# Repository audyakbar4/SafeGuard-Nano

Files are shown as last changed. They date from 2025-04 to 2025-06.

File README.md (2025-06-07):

# 🌱 MoodPot — *"Happy Plant, Happy You."*

[Baca dalam Bahasa Indonesia](README.md) | [🌐 Read in English](README_EN.md)

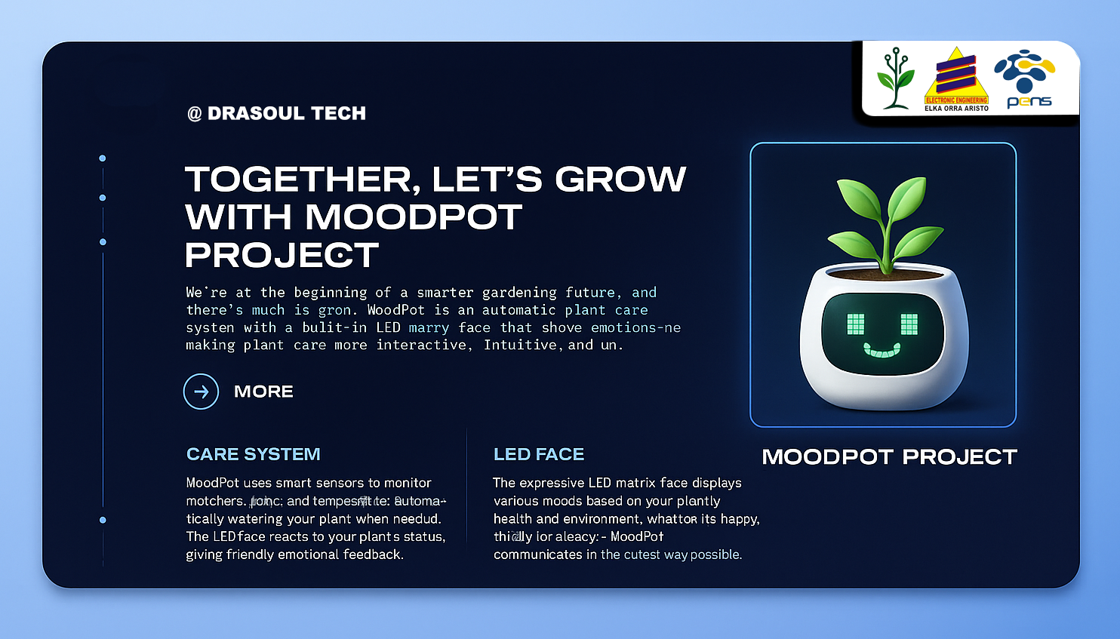
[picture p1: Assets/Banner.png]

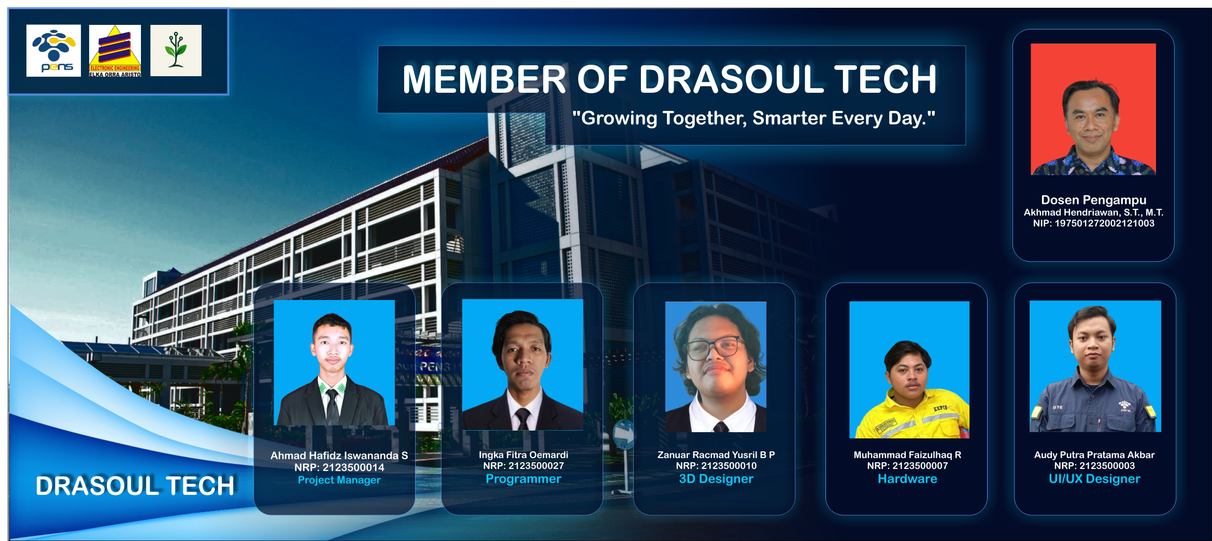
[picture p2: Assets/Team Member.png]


---

## 🎬 Commercial Video

Watch the demo (https://youtu.be/-DmmOEKwArI)

## Read The Book Now

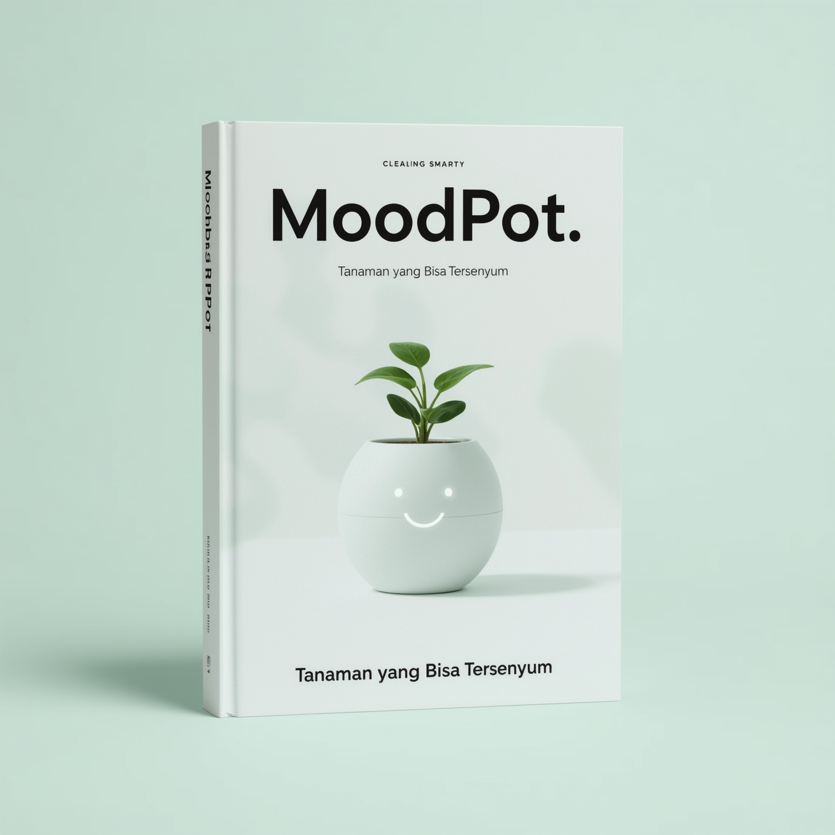
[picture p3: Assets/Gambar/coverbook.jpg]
Buka Buku (https://drive.google.com/file/d/1HuYGjgtTOYwcRgPvUPsH1EMrSk2Qgu1x/view?usp=drive_link)


## 🎬 Demo Video Project

Watch the demo (https://youtu.be/0xyM6YmwgGI)

##  Overview

🌱 MoodPot – Ketika Tanaman Bisa Bercerita Lewat Ekspresi

Pernah merasa bersalah karena lupa menyiram tanaman? Atau bingung kapan waktunya menyiram? MoodPot hadir sebagai sahabat tanaman yang bisa berbicara padamu lewat ekspresi wajah.

Bayangkan kamu pulang ke rumah setelah hari yang melelahkan. Di pojok ruangan, tanaman kesayanganmu sedang “menatap” dengan wajah sedih. Bukan karena marah—tapi karena ia haus. Tapi tenang, MoodPot sudah tahu apa yang harus dilakukan. Ia otomatis menyalakan pompa kecil dan memberi tanamanmu minuman yang dibutuhkannya.

Beberapa saat kemudian, wajahnya berubah ceria. Tanahnya lembap kembali, dan tanamanmu pun bahagia.

MoodPot bukan sekadar pot bunga. Ia adalah teman kecil yang mengingatkan kita bahwa merawat tanaman bisa menjadi pengalaman yang menyenangkan, komunikatif, dan penuh empati—bahkan untuk pemula sekalipun. Dengan sensor kelembapan tanah, ekspresi LED Matrix yang menggemaskan, dan sistem penyiraman otomatis, MoodPot menjadikan setiap interaksi kecil terasa berarti.

Karena tanaman juga punya cara untuk menyampaikan perasaannya—dan MoodPot menerjemahkannya untukmu.

---

## 🎯 Objectives

- 🔍 Mendeteksi kelembapan tanah secara otomatis menggunakan sensor.
- 😊 Memberikan feedback visual (wajah senang/datar/sedih) melalui LED Matrix.
- 💧 Menyiram tanaman secara otomatis ketika tanah kering.
- 💻 Menyediakan monitoring kelembapan secara real-time melalui UART ke komputer.

---

## 🧠 Background

Merawat tanaman sering kali menjadi tantangan, terutama bagi orang-orang sibuk atau yang belum terbiasa dengan kebutuhan dasar tanaman. Salah satu penyebab tanaman layu adalah kurangnya perhatian terhadap kelembapan tanah.

**MoodPot** memberikan solusi dengan menampilkan *"mood"* tanaman—apakah bahagia, cukup, atau sedih—berdasarkan kondisi tanah, membuat pengguna lebih peduli dan terlibat.

---

## 🖼️ Preview Presentasi



> Klik tombol di atas untuk membuka presentasi secara penuh di Canva.

---

## 🧾 Daftar Isi Presentasi

1. Latar Belakang & Masalah
2. Konsep MoodPot
3. Komponen yang Digunakan
4. Diagram Sistem
5. Demo & Visualisasi
6. Manfaat dan Pengembangan

---

## 🔧 Hardware Components

| Komponen | Fungsi |
|---|---|
| 🧠 Arduino Nano | Pengontrol utama |
| 🌱 Sensor Kelembapan | Membaca kadar air tanah |
| 😃 LED Matrix (MAX7219) | Menampilkan ekspresi wajah |
| 🔌 Relay Module | Mengendalikan pompa |
| 💦 Pompa DC 5V | Menyiram tanaman otomatis |
| 🔋 Baterai 18650 2S | Sumber daya portabel |

---

## 💻 Software Tools

- [Arduino IDE](https://www.arduino.cc/en/software)
- [KiCad](https://kicad.org/)
- [Figma](https://www.figma.com/)
- [TinkerCAD](https://www.tinkercad.com/)
- [Thingiverse](https://www.thingiverse.com/)
- [Visual Studio Code](https://code.visualstudio.com/)

---

## 🧭 System Diagram

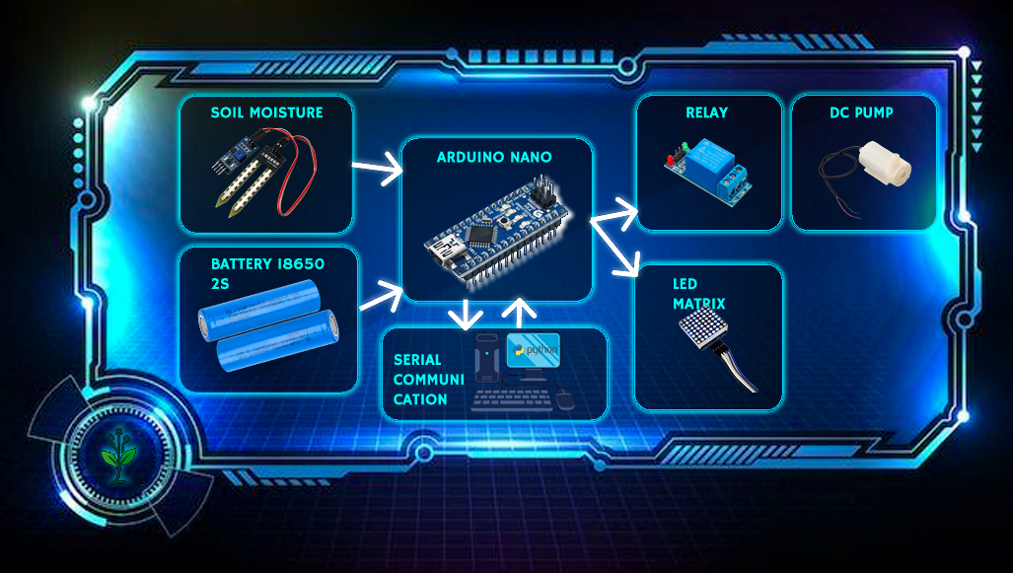
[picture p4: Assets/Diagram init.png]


## Schematic

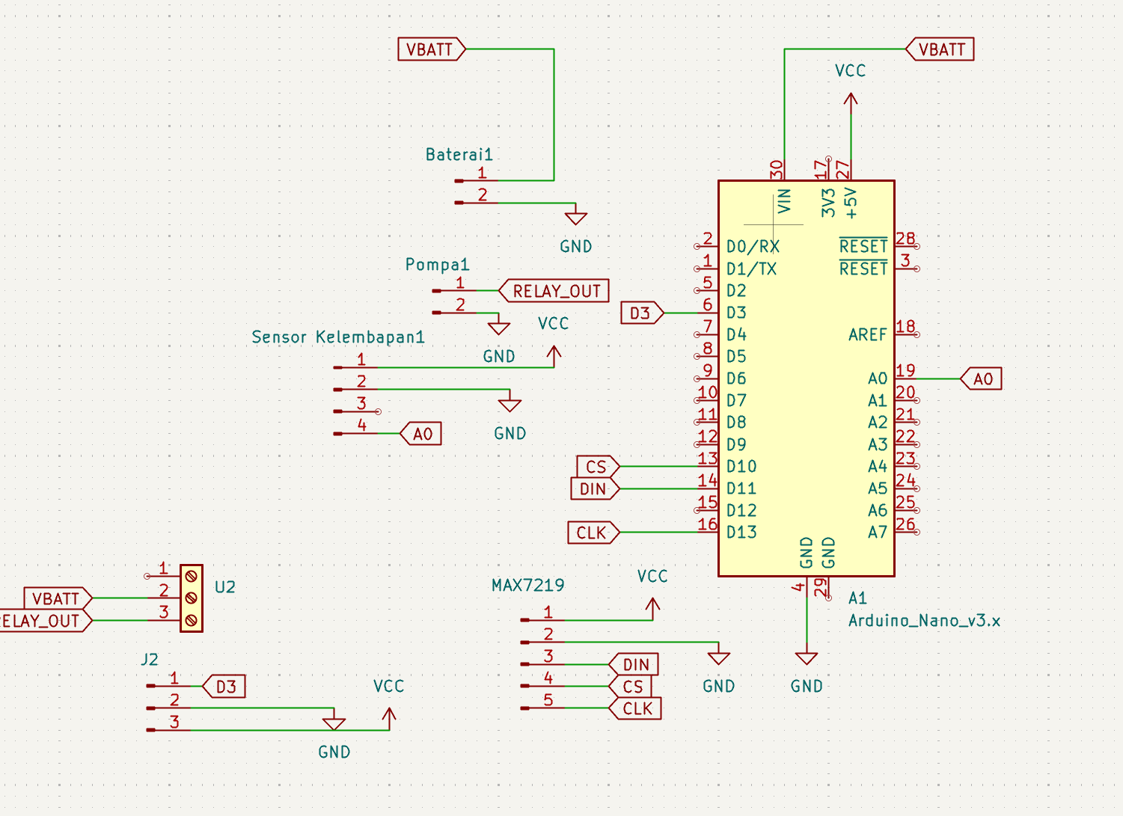
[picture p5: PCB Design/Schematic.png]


## Layout

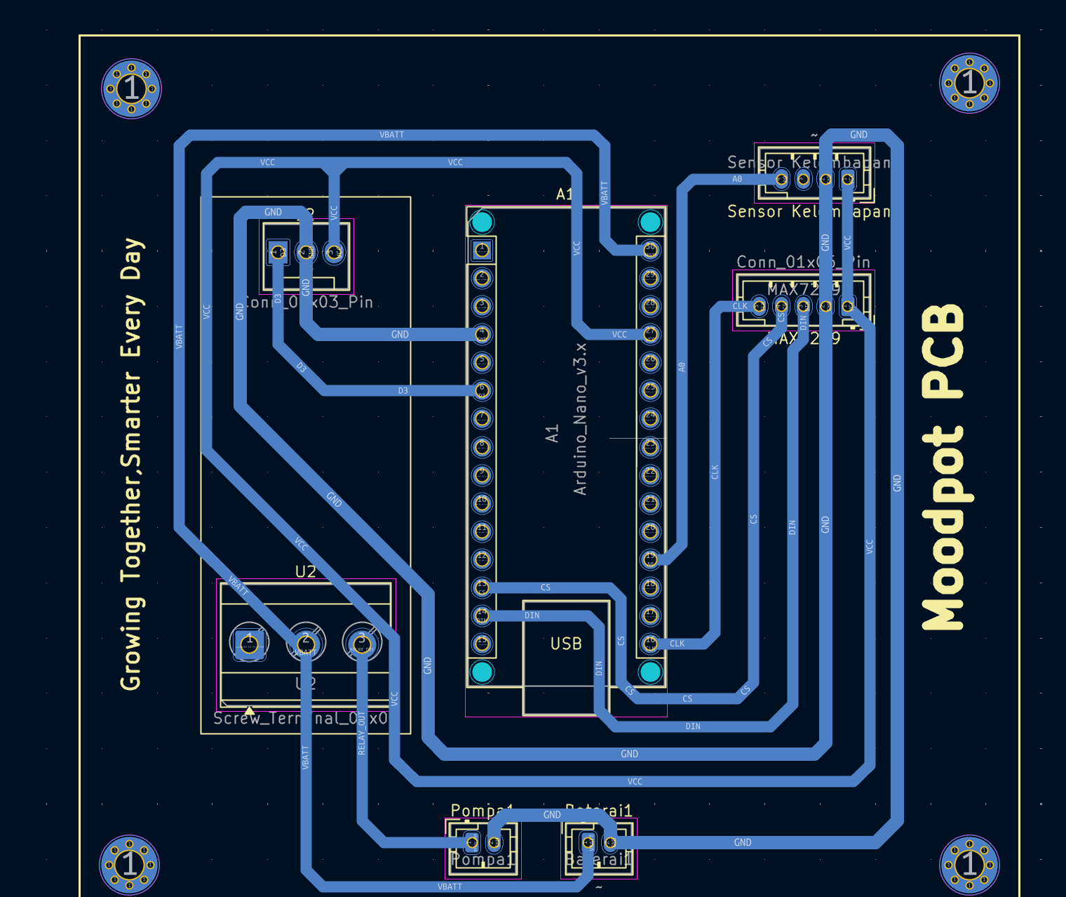
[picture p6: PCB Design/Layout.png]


## 3D PCB

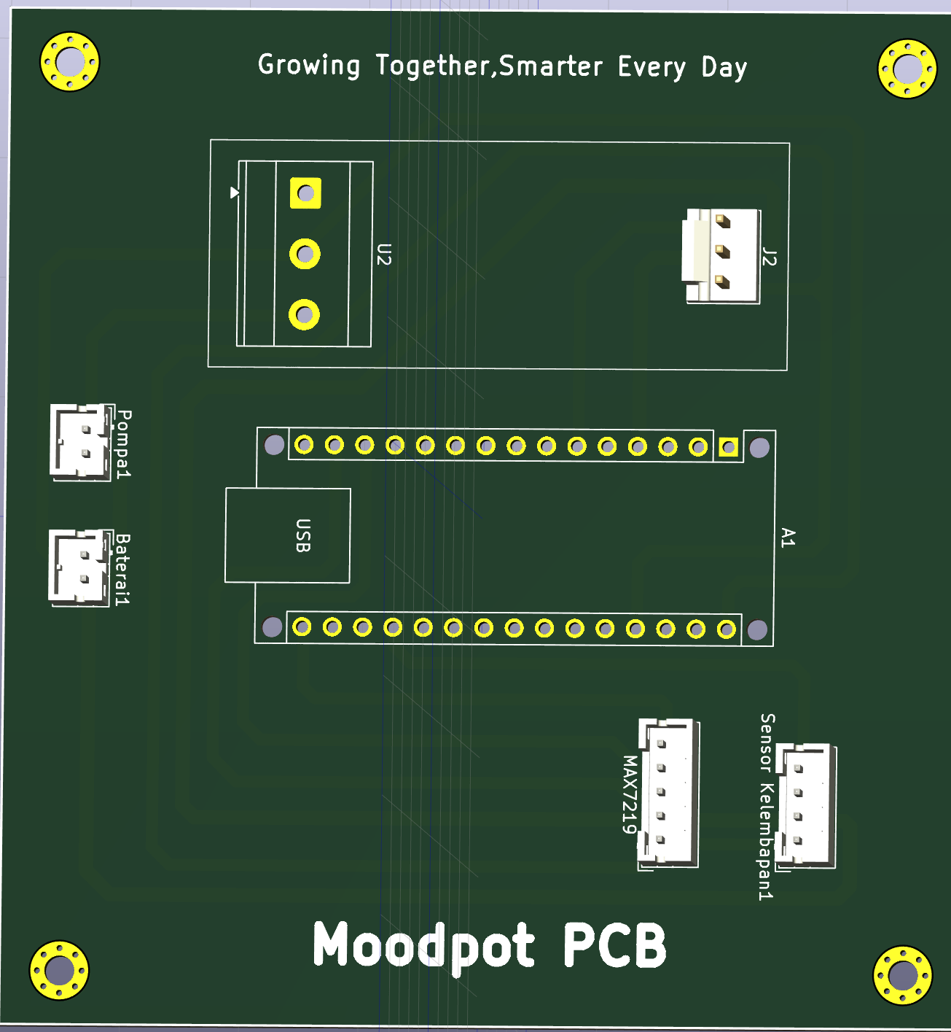
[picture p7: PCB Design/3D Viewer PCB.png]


## Tampak Dalam
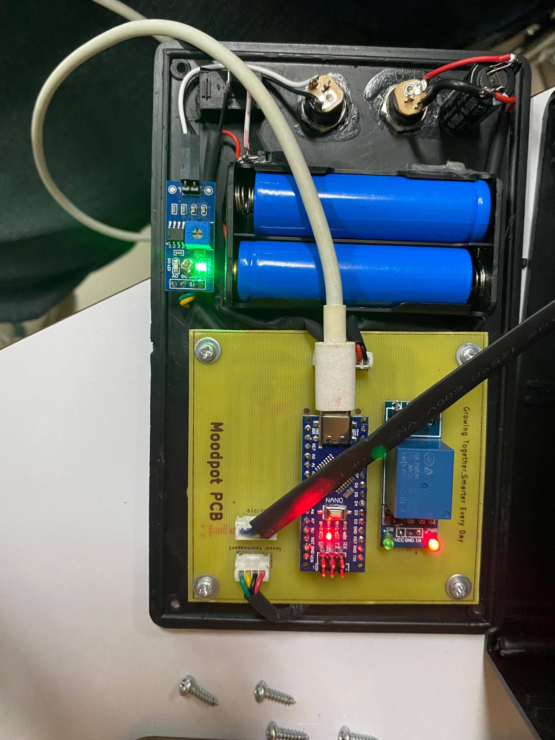
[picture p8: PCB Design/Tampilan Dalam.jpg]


---

## 💡 Simulasi Proyek



🔗 **Tautan Proyek Wokwi**  
[https://wokwi.com/projects/431816390638291969](https://wokwi.com/projects/431903301521434625)

📁 **Dokumentasi Proyek (Google Drive)**  
[https://drive.google.com/drive/folders/1GqONTiI6WEsIznY9d5Q_FcgnjMObSm_b?usp=drive_link](https://drive.google.com/drive/folders/1GqONTiI6WEsIznY9d5Q_FcgnjMObSm_b?usp=drive_link)

## 📄 Desain 3D

📁 **Tutorial Desain 3D (Google Drive)**

[👉 Klik di sini untuk membuka folder Google Drive](https://drive.google.com/drive/folders/1GnPXin400DgNMjtPwBu-FTDF2DJWISpB?usp=drive_link)

🔗 **Desain 3D Vol 1**  
https://www.thingiverse.com/thing:7030558

🔗 **Desain 3D Vol 2**  
https://www.thingiverse.com/thing:7048423

🔗 **Desain 3D Vol **  
https://www.thingiverse.com/thing:7050436

---

## ⚙️ Working Principle

### 🔍 Pembacaan Kelembapan
- Sensor kelembapan tanah mengirim sinyal analog ke Arduino.
- Nilai tinggi → tanah kering; nilai rendah → tanah basah.

### 🧠 Pemrosesan oleh Arduino
- Arduino membaca sensor secara berkala dan membandingkan dengan nilai *threshold*.
- Keputusan diambil untuk menyiram atau tidak.

### 😃 Feedback Visual
- Tanah basah  → LED Matrix menampilkan wajah senang 😊
- Tanah Sedang → LED Matrix menampilkan wajah Datar  😑
- Tanah kering → LED Matrix menampilkan wajah sedih  😢

### 💧 Penyiraman Otomatis
- Jika tanah kering, relay mengaktifkan pompa air.
- Setelah tanah cukup lembap, pompa dimatikan otomatis.

---
## 🚀 Quick Start

MoodPot dikirim dalam kondisi siap pakai (plug and play). Berikut langkah cepat untuk langsung menggunakannya:

### 🪴 Langkah Penggunaan MoodPot:

1. **Isi Tangki Air**
   - siapkan wadah untuk tangki air, isi wadah air hingga penuh kemudian masukkan dc pump / pompa air kedalam wadah yang sudah terisi dengan air.

2. **Colokkan Power**
   - Sambungkan MoodPot ke sumber daya menggunakan kabel USB atau baterai 2S 18650 bawaan.

3. **Tancapkan Sensor ke Tanah**
   - Pastikan sensor kelembapan sudah tertancap di dalam tanah pada pot tanaman kamu.

4. **Lihat Ekspresi Wajah**
   - MoodPot akan langsung menyala dan menampilkan ekspresi wajah:
     - 😊 Bahagia → Tanah lembap, tidak perlu disiram
     - 😐 Netral → Tanah mulai mengering, bersiap menyiram
     - 😢 Sedih → Tanah kering, pompa menyiram otomatis

5. **Selesai**
   - MoodPot akan bekerja otomatis 24/7 tanpa perlu pengaturan manual.

> 💡 Tips: Periksa tangki air setiap beberapa hari agar tidak kehabisan air.

---

## 👨‍💻 Team — Drasoul.Tech

| NRP | Nama Lengkap | Tanggung Jawab |
|---|---|---|
| 2123500003  | Audy Putra Pratama Akbar | UI/UX Designer |
| 2123500007  | Muhammad Faizulhaq R | Hardware |
| 2123500010  | Zanuar Rachmat Yusril B.P. | 3D Designer |
| 2123500014  | Ahmad Hafidz Iswananda S | Project Manager / Hardware  |
| 2123500027  | Ingka Fitra Oemardi | Programmer |

---
## 🌍 Showcase 

- 📢 Dipresentasikan di **PENS Workshop Mikrokontroler 2025**
- 🌟 Ditampilkan dalam demo terbuka oleh dosen pembimbing
- 👨‍🏫 Mendapat feedback positif dari pengajar dan rekan sejawat

📸 Dokumentasi Kegiatan:
[👉 Klik di sini untuk melihat dokumentasi](https://drive.google.com/drive/folders/1GqONTiI6WEsIznY9d5Q_FcgnjMObSm_b?usp=drive_link)

---

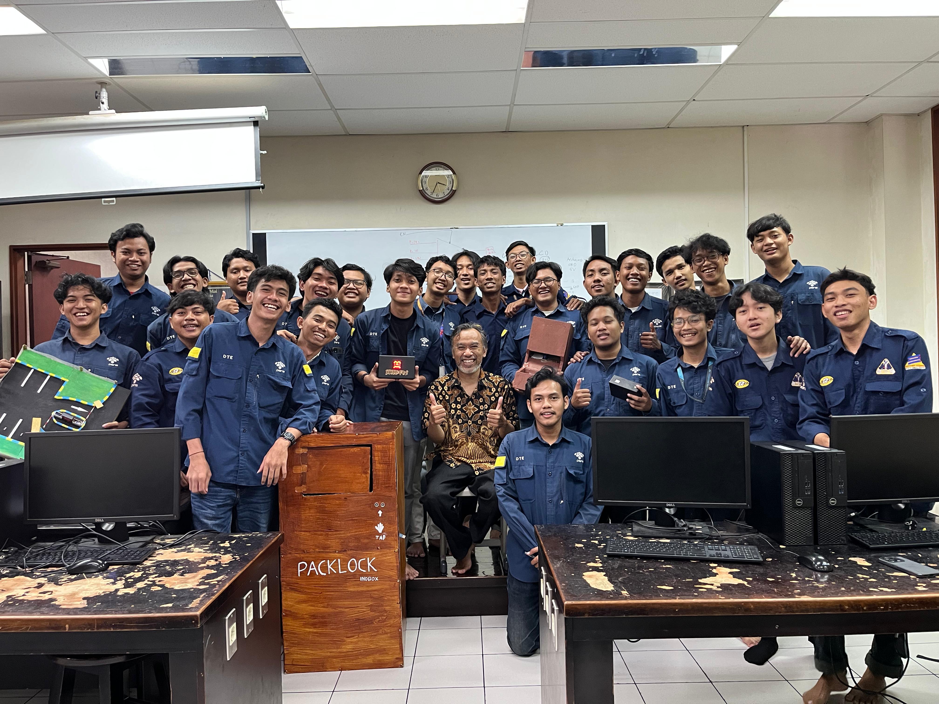
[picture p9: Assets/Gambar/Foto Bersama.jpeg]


## 🎓 Supported by

- 👨‍🏫 Dosen Pengampu: Akhmad Hendriawan, S.T., M.T.
- 📚 Mata Kuliah: Workshop Mikrokontroler
- 🏫 Institusi: Politeknik Elektronika Negeri Surabaya (PENS)
- 🧑‍🔧 Program Studi: Teknik Elektronika

---

## ✅ Future Improvements

- [ ] Tambahkan koneksi Bluetooth untuk kontrol dari HP
- [ ] Implementasi OLED display untuk info lebih lengkap
- [ ] Desain casing 3D cetak

---

## 📄 License

This project is licensed under the MIT License — see the [LICENSE](./LICENSE) file for details.

---

## 🙏 Credits

Developed with 💚 by **Drasoul.Tech**  
A project to bring life, tech, and plants together 🌿

## 📫 Contact Information

For inquiries related to this project — including collaborations, technical questions, or professional opportunities — feel free to reach out via email:

**📧 Email:** [yourname@example.com](mailto:yourname@example.com)

I aim to respond within 1–2 business days. Please include the project name in your subject line for faster reference.

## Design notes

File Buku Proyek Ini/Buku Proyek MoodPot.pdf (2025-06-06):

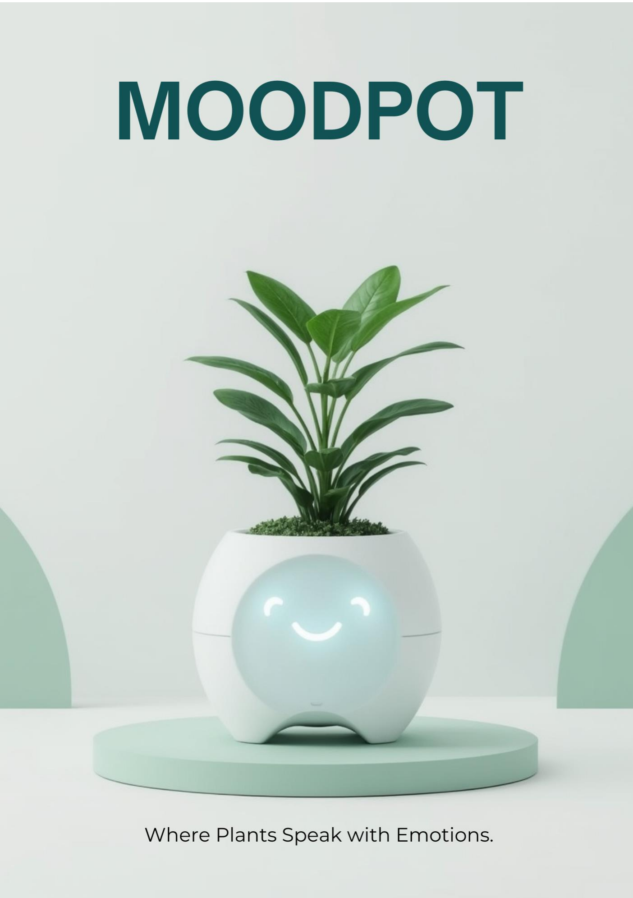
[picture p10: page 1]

Daftar Isi

BAB 1: Pendahuluan

BAB 2: Konsep dan Ideologi MoodPot

2.1 Inspirasi di Balik MoodPot

2.2 Filosofi "Tanaman Bisa Bercerita"

2.3 Konsep Interaksi Emosional antara Manusia dan Tanaman

2.4 Studi Kasus Penggunaan dalam Kehidupan Sehari-Hari

BAB 3: Perancangan Sistem MoodPot

3.1 Arsitektur Sistem secara Umum

3.2 Diagram Blok MoodPot

3.3 Alur Kerja MoodPot (Flowchart)

3.4 Skema dan Penjelasan Elektronik

BAB 4: Komponen Hardware

4.1 Arduino Nano: Otak dari MoodPot

4.2 Sensor Kelembapan Tanah

4.3 LED Matrix MAX7219: Ekspresi Wajah Tanaman

4.4 Pompa DC dan Relay: Mekanisme Penyiraman Otomatis

4.5 Sumber Daya: Baterai 18650 dan Manajemen Energi

BAB 5: Pemrograman MoodPot

5.1 Logika Program dan Penanganan Sensor

5.2 Menampilkan Ekspresi Wajah (Sad, Neutral, Happy)

5.3 Kontrol Pompa Berdasarkan Data Kelembapan

5.4 Monitoring Serial via UART

5.5 Optimalisasi dan Penanganan Error

BAB 6: Desain dan Estetika

6.1 Desain Fisik Pot dan Penempatan Komponen

6.2 Integrasi Teknologi dan Estetika

6.3 Desain UI Ekspresi LED Matrix

6.4 Visualisasi Figma dan TinkerCAD

BAB 7: Implementasi dan Pengujian

7.1 Proses Perakitan MoodPot

7.2 Pengujian Fungsi Otomatisasi Penyiraman

7.3 Respons Ekspresi terhadap Kelembapan

7.4 Studi Waktu Respons dan Efisiensi Air

7.5 Dokumentasi Proses Uji Lapangan

BAB 8: Dampak, Manfaat, dan Pengembangan

8.1 Pengaruh MoodPot terhadap Kebiasaan Merawat Tanaman

8.2 MoodPot untuk Edukasi Anak dan Pemula

8.3 Potensi Integrasi IoT dan Mobile App di Masa Depan

8.4 Pengembangan Ekspresi yang Lebih Kaya (Emotion Mapping)

8.5 Inovasi: MoodPot Versi Komunitas atau Sekolah

BAB 9: Penutup

9.1 Refleksi atas Proyek dan Pembelajaran

9.2 Saran untuk Pengguna dan Pengembang

9.3 Harapan ke Depan bagi MoodPot dan Proyek Serupa

Lampiran

- Kode Program Lengkap
- Skema Rangkaian
- Gambar PCB (jika ada)
- Tangkapan Layar Monitoring UART
- Daftar Komponen & Estimasi Biaya

# BAB 1

Merawat Tanaman di Era Digital
Di tengah deru kemajuan teknologi yang semakin pesat, kehidupan kita tak pernah lepas dari sentuhan inovasi. Mulai dari gawai cerdas hingga kendaraan otonom, semuanya dirancang untuk mempermudah setiap aspek kehidupan. Tak terkecuali dunia bercocok tanam. Dulu, merawat tanaman hanyalah tentang intuisi dan pengalaman. Kini, dengan hadirnya teknologi, kegiatan ini bisa menjadi lebih cerdas dan menyenangkan.
Bagi banyak orang, merawat tanaman, entah itu hamparan kebun yang luas atau sekadar pot bunga di beranda, bukan hanya sekadar hobi. Ada kepuasan tersendiri saat melihat tanaman tumbuh subur, bahkan ada manfaat psikologis dan ekologis yang tak ternilai. Namun, seringkali kesibukan harian, minimnya pengetahuan tentang kebutuhan spesifik tanaman, atau bahkan lupa, menjadi penghalang bagi kita untuk memberikan perhatian yang layak. Pernahkah Anda merasa bersalah karena tanaman kesayangan layu akibat telat disiram? Kita semua pernah mengalaminya.

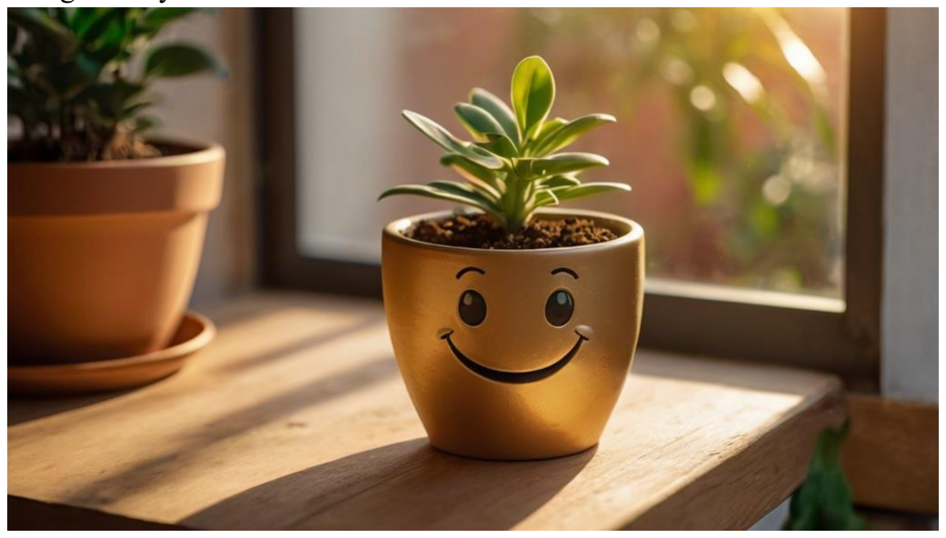
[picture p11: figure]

Di sinilah MoodPot hadir sebagai sebuah solusi inovatif dan empatik. Bayangkan sebuah pot tanaman yang bisa "berbicara" kepada Anda, bukan dengan suara, melainkan dengan ekspresi wajah! MoodPot adalah perpaduan cerdas antara teknologi mikrokontroler, sensor kelembapan tanah, dan layar LED Matrix yang mampu menampilkan ekspresi visual. Ini bukan sekadar alat penyiram otomatis biasa. MoodPot dirancang untuk membangun jembatan emosional antara Anda dan tanaman.

Ketika Tanaman Punya Ekspresi: Memahami Konsep MoodPot Melalui ekspresi wajah yang unik pada layar LED Matrix-nya, MoodPot
memberikan | gambaran | langsung
tentang kondisi tanaman. Sebuah
wajah | "sedih" | mungkin
menunjukkan bahwa tanaman Anda kehausan, dan begitu disiram, ia akan menampilkan wajah "bahagia" yang menggemaskan. Konsep ini melampaui fungsionalitas semata; ia menambahkan sentuhan emosional
yang | mengubah | pengalaman
merawat tanaman menjadi lebih
interaktif dan bermakna.

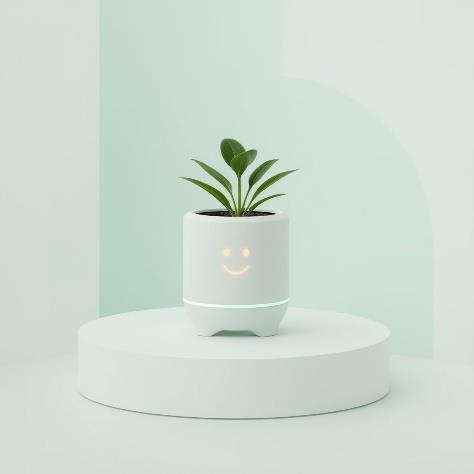
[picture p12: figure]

MoodPot bukan hanya untuk para ahli botani atau mereka yang punya "tangan dingin" dalam berkebun. Inovasi ini dapat menjadi alat edukatif yang luar biasa. Bayangkan anak-anak yang belajar tentang tanggung jawab dan empati dengan merawat tanaman yang bisa "mengekspresikan" perasaannya. Ini adalah cara yang menyenangkan untuk memahami pentingnya menjaga makhluk hidup, bahkan mereka yang tak bersuara sekalipun.

Merancang Jantung MoodPot: Sebuah Perjalanan Teknis
Di balik kesederhanaan ekspresi wajahnya, MoodPot menyimpan kompleksitas teknologi yang menarik. Dalam pengembangannya, kami menghadapi beberapa pertanyaan mendasar:
- Bagaimana cara MoodPot mendeteksi kelembapan tanah secara akurat dan otomatis? Kami perlu merancang sistem sensor yang peka terhadap kadar air dalam tanah.

- | Bagaimana ekspresi wajah ini bisa | muncul? Kami harus
memikirkan cara mengonversi data kelembapan menjadi visual yang mudah dipahami pada LED Matrix.
- Kapan tanaman harus disiram? Sistem harus mampu memicu penyiraman otomatis begitu tanah terdeteksi kering, tanpa perlu intervensi manusia.
- Bagaimana pengguna bisa memantau kondisi tanaman lebih detail? Kami ingin memberikan kemampuan untuk melihat data kelembapan secara real-time melalui antarmuka sederhana.
- Bagaimana memastikan sistem ini bekerja secara efisien, hemat energi, dan mudah digunakan oleh siapa saja? Ini adalah tantangan besar dalam membuat teknologi yang benar-benar bermanfaat.
Dengan menjawab pertanyaan-pertanyaan ini, kami bertujuan untuk mencapai beberapa hal:
- Meningkatkan kesadaran akan kebutuhan dasar tanaman, khususnya kelembapan tanah.
- Menerapkan teknologi mikrokontroler ke dalam solusi praktis dan edukatif yang bisa dimanfaatkan sehari-hari.
- Menciptakan media interaktif yang unik, menggugah empati antara manusia dan tanaman.
- Menyediakan solusi perawatan tanaman otomatis yang terjangkau dan mudah diimplementasikan.
- Memberikan pengalaman yang menyenangkan dan informatif bagi siapa pun yang ingin merawat tanaman, terutama bagi para pemula.

Manfaat yang Mengalir dari Sebuah Pot Cerdas
MoodPot dirancang untuk memberikan kemudahan dan nilai tambah. Beberapa manfaat nyata yang bisa Anda rasakan antara lain:
- Kemudahan merawat tanaman: Sangat cocok bagi Anda yang memiliki jadwal padat atau sering bepergian.
- | Menumbuhkan | rasa | tanggung jawab: | Interaksi dengan
"ekspresi" tanaman membantu menumbuhkan kepedulian terhadap
| makhluk hidup.
- Media edukatif: Menjadi cara yang efektif untuk memperkenalkan prinsip dasar elektronika, pemrograman, dan sensorik kepada anak-anak atau siapa pun yang ingin belajar.
- | Nilai estetika dan interaksi: Menambah | sentuhan unik dan lucu
| pada dekorasi rumah atau kantor Anda.
- Potensi pengembangan: Membuka pintu bagi inovasi lebih lanjut dalam bidang pertanian cerdas (smart agriculture) dan sistem
| rumah pintar (smart home).

Keterbatasan dalam Inovasi: Fokus MoodPot
Setiap inovasi memiliki batasannya sendiri. Untuk menjaga pengembangan MoodPot tetap terarah, kami menetapkan beberapa batasan:
- MoodPot fokus pada pendeteksian kelembapan tanah saja, tidak
| mengukur suhu atau nutrisi tanah.
- Sistem penyiraman otomatisnya menggunakan pompa DC 5V dengan volume air standar, tanpa mempertimbangkan kebutuhan
| spesifik berbagai jenis tanaman.
- Ekspresi visualnya ditampilkan pada satu buah LED Matrix 8x8 yang hanya menggambarkan tiga kondisi: bahagia, netral, dan
| sedih.
- Antarmuka monitoring data kelembapan hanya tersedia melalui koneksi serial (UART) dan belum mendukung koneksi nirkabel.
- MoodPot dikembangkan menggunakan Arduino Nano dan tidak dirancang untuk penggunaan komersial berskala besar.

Perjalanan Pengembangan MoodPot: Dari Ide ke Realita
Proses pengembangan MoodPot mengikuti sebuah metodologi yang terstruktur untuk memastikan hasil yang optimal. Tahapan yang kami lalui meliputi:
1. Studi Literatur: Mendalami kebutuhan dasar tanaman dan
| meninjau teknologi yang relevan.
2. Perancangan Sistem: Merancang detail hardware dan software
| MoodPot.
3. Implementasi dan Perakitan: Mewujudkan desain menjadi
| perangkat fisik dan memprogramnya.
4. Uji Coba dan Pengukuran: Menguji kinerja sistem secara
| menyeluruh.

5. Analisis dan Perbaikan: Menganalisis hasil uji coba dan melakukan perbaikan yang diperlukan.
6. Dokumentasi: Mendokumentasikan seluruh proses dan hasil dalam bentuk buku ini.

Peta Perjalanan Buku Ini
Buku ini akan membawa Anda menyelami lebih dalam setiap aspek MoodPot. Sistematika penulisan buku ini adalah sebagai berikut:
- Bab 1: Merawat Tanaman di Era Digital – Anda sedang membaca bab ini, yang memperkenalkan MoodPot, tujuan, manfaat, serta batasan pengembangannya.
- Bab 2: Memahami Fondasi: Teori di Balik MoodPot – Bab ini akan membahas teori dasar mengenai mikrokontroler, sensor kelembapan, LED Matrix, serta sistem penyiraman otomatis yang menjadi tulang punggung MoodPot.
- Bab 3: Blueprint MoodPot: Desain Hardware dan Software – Di sini, kita akan membahas detail rancangan perangkat keras dan perangkat lunak MoodPot.
- Bab 4: Membangun dan Menguji: Implementasi dan Uji Coba – Bab ini akan menjelaskan proses perakitan, pemrograman, dan pengujian sistem MoodPot secara praktis.
- Bab 5: Melihat Lebih Dalam: Analisis dan Pembahasan – Kita akan mengulas hasil pengujian, menganalisis performa, serta membahas kelebihan dan kekurangan sistem.
- Bab 6: Kesimpulan dan Langkah Selanjutnya – Bab terakhir ini akan merangkum kesimpulan dari proyek MoodPot dan memberikan saran untuk pengembangan lebih lanjut.
Mari kita lanjutkan perjalanan ini dan temukan bagaimana MoodPot bisa mengubah cara kita berinteraksi dengan tanaman!

### 1.1 Evolusi Teknologi dalam Perawatan Tanaman

Sejarah pertanian telah melalui transformasi besar. Dari teknik bercocok tanam manual pada masa prasejarah, manusia mulai mengenal sistem irigasi, pupuk alami, hingga akhirnya teknologi pertanian modern. Di masa Revolusi Industri, peralatan mekanis seperti traktor mempercepat pengolahan lahan. Memasuki era digital, inovasi seperti precision farming, sistem berbasis sensor, dan Internet of Things (IoT) mulai diterapkan.

Perawatan tanaman skala rumah pun ikut berevolusi. Pot konvensional kini dilengkapi alat pemantau kelembapan, penyiraman otomatis, hingga pencahayaan buatan yang disesuaikan dengan siklus pertumbuhan tanaman. MoodPot merupakan bagian dari tren ini, menghadirkan sistem perawatan tanaman yang cerdas, personal, dan intuitif. Tidak hanya memberi kenyamanan, tetapi juga mendekatkan manusia kembali dengan alam melalui teknologi.

Teknologi dalam pertanian rumah tangga sebelumnya hanya mencakup alat-alat dasar seperti semprotan manual, pot berlubang, atau sistem wick yang mengandalkan kapilaritas untuk menyerap air. Kini, kemajuan dalam miniaturisasi elektronik memungkinkan sistem pemantauan dan kontrol otomatis yang dulunya hanya tersedia di lahan pertanian besar. Sensor kelembapan tanah berbasis analog maupun digital kini dapat diproduksi secara massal dengan harga terjangkau dan akurasi yang memadai.

Salah satu bentuk evolusi yang
paling | revolusioner | adalah
kemampuan | sistem | untuk
mengumpulkan, | menganalisis,
dan merespon data secara real-time. Dalam konteks perawatan tanaman, hal ini berarti bahwa pot tanaman tidak lagi bersifat pasif, melainkan menjadi sistem aktif
yang | dapat | memberitahukan
kondisinya | kepada | pemilik.
MoodPot | merepresentasikan

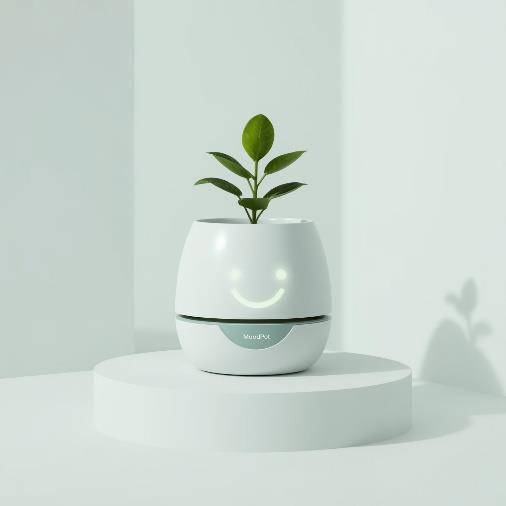
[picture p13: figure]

evolusi | ini | dengan | pendekatan | humanistik: | ia | tidak | hanya
menyampaikan data, tetapi menyampaikannya dalam bentuk ekspresi wajah.

Lebih jauh, sejarah perkembangan teknologi perawatan tanaman juga mencakup penggunaan sistem hidroponik dan aeroponik. Sistem ini memungkinkan tanaman tumbuh tanpa tanah, menggunakan larutan nutrisi dan pengabutan akar. Sementara MoodPot masih bergantung pada tanah sebagai media tanam, prinsip pemantauan otomatis tetap relevan dalam semua jenis sistem budidaya.

Tren terbaru dalam teknologi perawatan tanaman mengarah pada integrasi Artificial Intelligence (AI). AI dapat mempelajari pola penyiraman, mencatat respon tanaman, dan memprediksi kebutuhan air berdasarkan cuaca atau musim. Meskipun MoodPot saat ini belum memiliki AI, platform ini dapat menjadi basis pengembangan teknologi ke arah tersebut. Dalam tahap lanjut, MoodPot bisa berfungsi layaknya 'dokter digital' bagi tanaman.;

Evolusi teknologi ini juga mendorong munculnya komunitas-komunitas online yang mendiskusikan perawatan tanaman pintar. Forum-forum ini menjadi tempat berbagi desain, firmware, dan pengalaman dalam merakit sistem serupa MoodPot. Komunitas maker dan open-source memainkan peran vital dalam menyebarluaskan teknologi ini, memastikan bahwa setiap orang, termasuk pelajar dan penghobi, dapat mengakses dan memahami teknologi canggih secara gratis.

Dengan menyadari evolusi ini, MoodPot bukan hanya sekadar alat bantu penyiraman, melainkan bagian dari gelombang transformasi digital yang lebih besar dalam dunia pertanian urban. Ia menunjukkan bahwa teknologi tidak harus rumit untuk menjadi bermanfaat. Dengan pendekatan sederhana namun berdampak, MoodPot menegaskan bahwa masa depan pertanian bisa dimulai dari meja kerja, ruang tamu, atau kamar tidur siapa saja.

### 1.2 Tantangan Merawat Tanaman di Era Modern

Gaya hidup urban yang
serba cepat sering kali
menyisakan sedikit waktu
untuk | aktivitas | seperti
berkebun. Banyak penghuni
kota tinggal di apartemen
dengan | lahan | terbatas.
Selain itu, stres dan tekanan

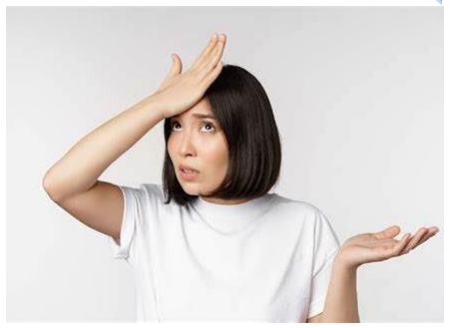
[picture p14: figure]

pekerjaan menyebabkan aktivitas merawat tanaman menjadi terlupakan. Akibatnya, banyak tanaman hias di rumah mati bukan karena penyakit, melainkan karena kelalaian perawatan.

MoodPot menjadi solusi pragmatis untuk tantangan ini. Sistem otomatisnya meringankan beban pengguna dalam menyiram tanaman, sementara ekspresi visualnya membangun kedekatan emosional. Ia bukan hanya alat bantu, melainkan juga pengingat, penghibur, dan pelengkap interior ruangan yang hidup.

### 1.3 Signifikansi Psikologis dan Edukatif MoodPot

Interaksi dengan tanaman terbukti memberi efek terapeutik. Beberapa penelitian menyatakan bahwa merawat tanaman mampu menurunkan tingkat stres, meningkatkan fokus, dan bahkan meredakan kecemasan. MoodPot menguatkan pengalaman ini dengan menambahkan elemen ekspresi.

Bagi anak-anak, MoodPot dapat menjadi alat pembelajaran yang menarik untuk memahami konsep air, sensor, emosi, dan tanggung jawab. Dalam konteks pendidikan STEM (Science, Technology, Engineering, Mathematics), proyek ini memperkenalkan dunia pemrograman dan elektronika secara aplikatif dan menyenangkan.

### 1.4 Integrasi MoodPot dalam Gaya Hidup Smart Home

MoodPot berpotensi menjadi bagian dari ekosistem rumah pintar. Dengan menambahkan modul WiFi seperti ESP8266 atau ESP32, sistem dapat terhubung ke internet. Pengguna bisa memantau kondisi tanaman lewat smartphone, menerima notifikasi saat tanaman "haus", bahkan mengendalikan penyiraman dari jarak jauh.

MoodPot juga bisa disambungkan ke dashboard pemantauan berbasis web atau aplikasi Android, memperluas fungsionalitas dan kenyamanan pengguna. Dalam jangka panjang, integrasi dengan asisten virtual seperti Alexa atau Google Assistant dapat menambah pengalaman interaktif dan otomatisasi lebih lanjut.

### 1.5 Human-Centered Design dan Pendekatan Empatik

Filosofi desain MoodPot berpusat pada manusia. Setiap elemen dirancang untuk mudah dipahami dan dioperasikan oleh pengguna awam. Penggunaan ekspresi wajah pada LED Matrix bukan hanya fitur estetika, melainkan sarana komunikasi intuitif. Manusia lebih mudah mengenali dan merespons ekspresi daripada angka statistik.

Pendekatan ini selaras dengan prinsip psikologi desain: mengedepankan kenyamanan, kejelasan pesan, dan pengalaman emosional positif. MoodPot bukan hanya alat teknis, tetapi juga media komunikasi antara manusia dan tanaman yang penuh makna.

### 1.6 Potensi Pengembangan Ke Depan

MoodPot memiliki banyak potensi untuk dikembangkan lebih lanjut:

- Penambahan fitur AI untuk analisis perilaku penyiraman pengguna dan prediksi kebutuhan air berdasarkan musim.
- Modul pengenalan suara untuk menerima perintah pengguna secara verbal.

- Kamera mini untuk mengenali jenis tanaman dan mengadaptasi jadwal penyiraman sesuai spesifikasi botani.
- Integrasi dengan sistem monitoring pertanian mini berbasis cloud.
- Desain ulang bentuk fisik pot agar lebih modular, estetis, dan ergonomis.

Dengan roadmap yang jelas, MoodPot dapat berkembang menjadi platform pembelajaran, solusi smart gardening, dan bahkan produk komersial yang menyasar pasar urban, edukatif, dan hobiis.

# BAB 2

BAB 2: TINJAUAN PUSTAKA

### 2.1 Mikrokontroler Arduino

Arduino merupakan platform
elektronik | open-source
berbasis perangkat keras dan perangkat lunak yang mudah
digunakan. | Platform | ini
dirancang untuk memudahkan
siapa | pun—baik | pemula
maupun | profesional—untuk
membuat | proyek | interaktif
berbasis | elektronik | dan

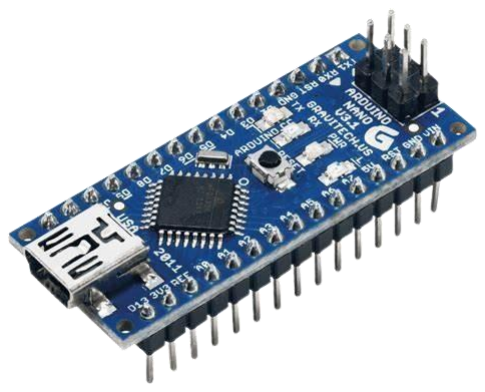
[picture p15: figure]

mikrokontroler. Salah satu keunggulan utama dari Arduino adalah kemampuannya untuk diprogram dengan bahasa yang sederhana serta komunitas global yang sangat aktif. Komunitas ini memberikan dukungan dokumentasi, contoh kode, hingga berbagai diskusi forum yang sangat membantu dalam proses pengembangan.

Arduino Nano merupakan varian Arduino yang berukuran kecil, namun memiliki kemampuan yang tidak kalah dengan varian lainnya seperti Arduino Uno. Dengan dimensi hanya sekitar 1,8 x 4,5 cm, papan ini sangat cocok untuk proyek dengan ruang terbatas seperti MoodPot. Arduino Nano menggunakan mikrokontroler ATmega328, memiliki 14 pin digital input/output (di mana 6 pin dapat digunakan sebagai PWM output), 8 input analog, serta konektivitas USB mini untuk pemrograman. Keunggulan lain dari Arduino Nano adalah konsumsi dayanya yang rendah dan kompatibilitasnya dengan berbagai sensor dan modul yang tersedia di pasaran.

Dalam proyek MoodPot, Arduino Nano digunakan sebagai otak dari sistem. Ia bertugas membaca data dari sensor kelembapan tanah, mengontrol tampilan ekspresi pada LED Matrix, serta mengaktifkan pompa penyiram otomatis berdasarkan logika yang telah diprogram. Kemampuan multitasking dari mikrokontroler ini sangat mendukung sistem MoodPot yang menggabungkan input dan output secara simultan dalam satu perangkat kompak. Selain itu, fleksibilitas dalam pemrograman memungkinkan integrasi fitur tambahan di masa depan, seperti koneksi ke jaringan WiFi atau Bluetooth untuk sistem notifikasi jarak jauh.

### 2.2 Sensor Kelembapan Tanah

Sensor kelembapan tanah adalah komponen penting dalam sistem pertanian cerdas maupun perangkat
perawatan | tanaman | otomatis.
Sensor ini bekerja dengan prinsip konduktivitas: tanah yang lembap
memiliki | konduktivitas | lebih
tinggi dibandingkan tanah yang kering. Dengan demikian, sensor dapat mengukur resistansi antara dua probe yang ditanam di tanah

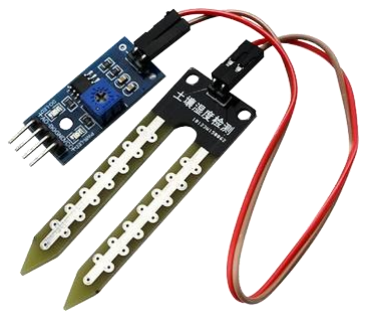
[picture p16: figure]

dan mengubahnya menjadi data digital atau analog.

Terdapat dua jenis utama sensor kelembapan tanah yang umum digunakan, yaitu:

1. Sensor Analog – Menghasilkan output tegangan yang sebanding dengan tingkat kelembapan. Semakin tinggi kelembapan, semakin besar tegangan yang dihasilkan.
2. Sensor Digital – Menghasilkan sinyal HIGH atau LOW tergantung ambang batas kelembapan yang telah ditentukan sebelumnya.

Dalam MoodPot, digunakan sensor analog agar pembacaan kelembapan dapat diinterpretasikan dalam bentuk level (bukan hanya dua kondisi ON/OFF). Data dari sensor ini diproses oleh Arduino Nano dan menjadi dasar dalam menentukan ekspresi wajah pada LED Matrix serta pemicu penyiraman otomatis. Penggunaan sensor analog memberikan hasil yang lebih presisi dan memungkinkan pengaturan ambang batas yang lebih fleksibel.

Kalibrasi sensor juga menjadi langkah penting. Kondisi lingkungan seperti suhu, jenis tanah, dan kadar garam dapat mempengaruhi pembacaan sensor. Oleh karena itu, dilakukan kalibrasi untuk menentukan nilai ambang antara kondisi "basah", "lembap", dan "kering" yang kemudian direpresentasikan dalam ekspresi MoodPot. Kalibrasi dilakukan dengan mengamati pembacaan sensor pada berbagai kondisi tanah, lalu menentukan nilai referensi yang relevan untuk sistem.

### 2.3 LED Matrix

LED Matrix adalah susunan LED dalam baris dan kolom yang digunakan untuk menampilkan teks, angka, atau gambar
sederhana. | Dalam | proyek | ini,
digunakan LED Matrix 8x8, yaitu tampilan dengan 8 baris dan 8 kolom LED, total 64 titik cahaya yang dapat dikontrol secara individual.

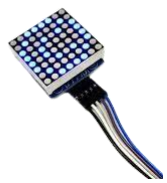
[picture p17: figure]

Untuk mengontrol LED Matrix, biasanya digunakan IC driver seperti MAX7219. IC ini memungkinkan pengguna untuk mengontrol hingga 8 digit (baris/kolom) LED Matrix hanya dengan beberapa pin dari mikrokontroler. Kelebihan dari penggunaan MAX7219 adalah efisiensi dalam wiring dan pengolahan data tampilan.

Dalam MoodPot, LED Matrix digunakan sebagai media komunikasi visual. Tiga ekspresi dasar yang digunakan adalah:

- Wajah Bahagia: Menunjukkan kondisi tanaman sehat dan tanah cukup lembap.
- Wajah Netral: Menunjukkan kondisi normal atau peralihan.

- Wajah Sedih: Menunjukkan kondisi tanah kering dan tanaman membutuhkan air.

Penggunaan ekspresi ini memberikan pendekatan human-centered design, di mana pengguna tidak perlu membaca angka atau grafik untuk memahami kondisi tanaman. Efek psikologis dari ekspresi visual ini juga membantu membentuk keterikatan emosional antara manusia dan tanaman, menjadikan perawatan tanaman sebagai pengalaman yang menyenangkan dan interaktif.

### 2.4 Sistem Penyiraman Otomatis

Sistem penyiraman otomatis pada MoodPot menggunakan pompa air mini DC 5V yang dikontrol langsung oleh Arduino melalui transistor sebagai saklar elektronik. Sistem ini bekerja berdasarkan logika: jika nilai kelembapan tanah berada di bawah ambang yang ditentukan, maka pompa akan aktif selama beberapa detik untuk menyiram tanaman.

Beberapa komponen penting dalam sistem ini antara lain:

- Pompa Air Mini DC 5V – Bertugas memindahkan air dari tangki ke pot tanaman.
- Transistor (misalnya TIP120 atau 2N2222) – Bertindak sebagai saklar elektronik yang menghubungkan atau memutus arus ke pompa.
- Dioda Flyback – Mencegah arus balik dari motor ke rangkaian Arduino.
- Resistor dan MOSFET – Untuk mengatur arus dan menghindari lonjakan tegangan.

Sistem ini juga dirancang agar hemat energi. Penyiraman dilakukan dalam durasi singkat dan hanya ketika diperlukan, berdasarkan data sensor. Ini membuat MoodPot efisien dan cocok digunakan dalam jangka
panjang | tanpa | pengawasan | terus-menerus. | Sistem | ini | juga
memungkinkan peningkatan ke depan seperti pengaturan jadwal penyiraman berbasis waktu atau kendali berbasis aplikasi.

### 2.5 Internet of Things (IoT) dalam Pertanian Cerdas

Internet of Things (IoT) merujuk pada konsep menghubungkan perangkat fisik ke internet agar dapat saling bertukar data secara otomatis. Dalam konteks pertanian, IoT memungkinkan monitoring dan pengendalian lingkungan pertanian dari jarak jauh.

Penerapan IoT dalam pertanian cerdas antara lain:

- Monitoring kelembapan, suhu, dan intensitas cahaya secara real-time.
- Pengendalian otomatis sistem irigasi.
- Pengiriman notifikasi ke smartphone pengguna.
- Integrasi dengan sistem analitik dan kecerdasan buatan (AI).

Untuk MoodPot, potensi integrasi IoT sangat besar. Dengan modul WiFi seperti ESP8266 atau ESP32, MoodPot dapat mengirimkan data kelembapan ke cloud, menampilkan grafik pertumbuhan tanaman, bahkan menerima perintah penyiraman dari aplikasi seluler. Integrasi ini
membuka | peluang | untuk | pengembangan | lebih | lanjut | seperti
pengumpulan data historis, analisis prediktif, hingga pengenalan pola penyiraman berdasarkan musim atau jenis tanaman.

### 2.6 Penelitian Terkait

Beberapa penelitian dan proyek sebelumnya yang relevan dengan MoodPot antara lain:

- Smart Plant Monitoring System using Arduino and IoT oleh mahasiswa Universitas XYZ (2020), yang menggabungkan sensor suhu, kelembapan, dan konektivitas Bluetooth. Penelitian ini menunjukkan bahwa sistem monitoring tanaman dapat meningkatkan efektivitas perawatan hingga 40%.
- Automated Irrigation using Moisture Sensor oleh peneliti ABC (2019), yang menunjukkan efisiensi penggunaan air sebesar 30% dengan sistem otomatis. Efisiensi ini menjadi penting dalam konteks urban farming dan konservasi air.
- Plant Emotion Simulation via LED Expressions oleh komunitas maker internasional, yang meneliti efek psikologis dari pemberian "kepribadian" pada pot tanaman. Proyek ini menjadi dasar pengembangan MoodPot dalam hal ekspresi dan interaksi visual.

MoodPot membedakan dirinya dengan menekankan aspek empatik dan ekspresif dalam interaksi manusia-tanaman. Penggabungan teknologi, edukasi, dan komunikasi visual menjadikan proyek ini unik dan multifungsi. Selain sebagai alat bantu perawatan tanaman, MoodPot juga berfungsi sebagai sarana edukatif untuk anak-anak, media pembelajaran STEM, serta dekorasi interaktif yang memperkaya lingkungan rumah atau ruang kelas.

### 2.7 Tantangan dan SolusiImplementasi MoodPot

Dalam merancang dan mengimplementasikan sistem seperti MoodPot, berbagai tantangan teknis dan non-teknis dapat muncul. Beberapa tantangan utama antara lain:

- | Keterbatasan | Daya: | MoodPot | yang | bersifat | portable
memerlukan konsumsi daya rendah. Solusinya adalah memilih komponen hemat energi dan merancang sistem sleep mode ketika tidak aktif.
- Keandalan Sensor: Sensor kelembapan tanah dapat rusak atau memberikan hasil tidak akurat. Diperlukan kalibrasi berkala dan kemungkinan sistem backup.
- Komunikasi Pengguna: Tidak semua pengguna paham teknologi. Penggunaan ekspresi wajah dan desain antarmuka sederhana membantu menjembatani kesenjangan ini.
- Kapasitas Memori Arduino: Karena Arduino Nano memiliki memori terbatas, optimalisasi kode dan penggunaan library efisien menjadi kunci.

Dengan pendekatan modular, pengujian iteratif, dan feedback pengguna,
tantangan-tantangan | ini | dapat | diatasi | secara | bertahap | untuk
menghasilkan produk yang andal dan menyenangkan digunakan.

### 2.8 Studi Kasus Penggunaan MoodPot di Lingkungan Nyata

Sebagai contoh implementasi, MoodPot telah diuji coba pada beberapa skenario:

- Penggunaan di Sekolah Dasar: MoodPot menjadi alat pembelajaran STEM bagi siswa. Mereka belajar tentang sensor, logika pemrograman, dan pentingnya merawat tanaman.
- Digunakan oleh Pekerja Kantoran: MoodPot membantu mereka tetap terhubung dengan tanaman meskipun sibuk, memberikan pengingat visual untuk menyiram tanaman.

- Penerapan di Rumah Lansia: Memberikan hiburan dan aktivitas ringan dengan interaksi emosional dari ekspresi LED Matrix.

Hasil studi menunjukkan bahwa MoodPot tidak hanya meningkatkan kesadaran terhadap perawatan tanaman, tetapi juga berdampak positif terhadap kesejahteraan emosional pengguna.

### 2.9 Perbandingan dengan Produk Serupa di Pasaran

Beberapa produk serupa di pasaran seperti Click & Grow, Xiaomi Smart Flower Pot, atau Parrot Flower Power menawarkan pemantauan tanaman. Namun, terdapat beberapa perbedaan:

- Harga: MoodPot jauh lebih murah karena dibuat dari komponen open-source.
- Ekspresi Emosional: Produk komersial lebih fokus pada data, sedangkan MoodPot menekankan pendekatan empatik.
- Customisasi: Pengguna dapat memodifikasi MoodPot sesuai kebutuhan karena desain dan kodenya terbuka.

Dengan demikian, MoodPot menempati posisi unik sebagai perangkat edukatif, personal, dan ekonomis.

### 2.10 Potensi Pengembangan Lanjutan

MoodPot memiliki potensi besar untuk dikembangkan lebih jauh. Beberapa arah pengembangan ke depan meliputi:

- Integrasi AI: Penambahan algoritma untuk mengenali pola kelembapan dan memberikan saran optimal.
- Deteksi Suara: Tanaman yang "merespons" suara pengguna, meningkatkan interaktivitas.
- Pengenalan Tanaman: MoodPot dapat mendeteksi jenis tanaman dan menyesuaikan logika perawatan.

- | Konektivitas Cloud: Sinkronisasi ke | aplikasi mobile dan
| pencatatan riwayat penyiraman.
- Ekosistem Pertanian Mini: MoodPot sebagai bagian dari jaringan perangkat perawatan tanaman kecil untuk pendidikan
| atau penelitian.

Dengan pendekatan open-source dan keterlibatan komunitas, MoodPot dapat terus berevolusi menjadi solusi cerdas yang semakin kompleks namun tetap human-friendly.

# BAB 3

### 3.1 Konsep Sistem MoodPot

MoodPot adalah sebuah inovasi sistem monitoring tanaman yang dirancang dengan pendekatan unik: menyampaikan kebutuhan tanaman melalui ekspresi visual. Sistem ini mengubah data kelembaban tanah menjadi simbol ekspresi wajah yang ditampilkan melalui layar, sehingga pengguna dapat langsung memahami kondisi tanaman secara intuitif. Konsep ini tidak hanya memberikan kemudahan monitoring, tetapi juga mempererat hubungan emosional antara manusia dan tanaman.

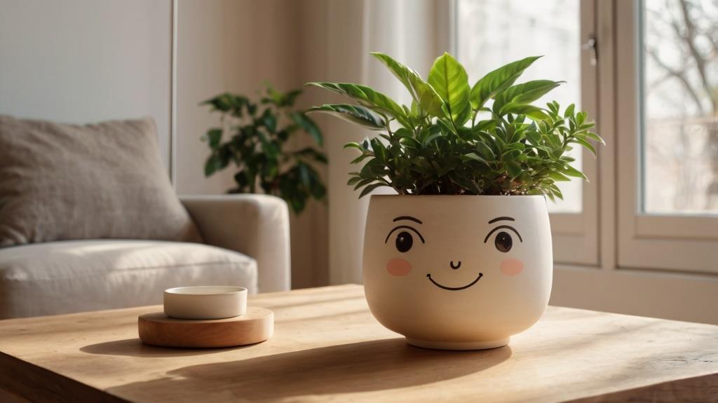
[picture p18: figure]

Berbeda dari sistem monitoring tanaman konvensional yang hanya menampilkan angka atau indikator teknis, MoodPot mengkomunikasikan informasi dengan cara yang lebih manusiawi. Misalnya, ketika tanah terlalu kering, layar akan menampilkan ekspresi sedih atau menangis; sebaliknya, jika kelembaban tanah berada dalam rentang ideal, ekspresi bahagia akan muncul. Konsep ini mengedepankan aspek edukatif dan interaktif, menjadikan teknologi lebih menyatu dengan kehidupan sehari-hari.

Prinsip kerja utama MoodPot adalah membaca data analog dari sensor kelembaban tanah, memproses nilai tersebut di mikrokontroler (Arduino Nano), dan menampilkan hasil interpretasinya dalam bentuk ekspresi visual pada layar OLED atau LED matrix. Dengan hanya menggunakan satu jenis sensor, MoodPot mampu menyederhanakan sistem tanpa mengorbankan fungsionalitas intinya.

Kelebihan dari pendekatan ini adalah:

- Kesederhanaan: hanya membutuhkan sedikit komponen, mudah dirakit dan hemat energi.
- Interaktif: memberikan pengalaman menyenangkan dan personal dalam merawat tanaman.

- Informatif: menyajikan data penting dalam bentuk visual yang mudah dipahami semua kalangan.

Konsep MoodPot sangat cocok diterapkan di lingkungan rumah, sekolah, atau kantor, sebagai alat bantu edukasi maupun elemen dekoratif cerdas. Dengan menggabungkan elemen teknologi, emosi, dan ekologi, MoodPot bukan hanya alat, tapi juga media komunikasi antara manusia dan tanaman.

### 3.2 Diagram Blok Sistem

Untuk memahami bagaimana MoodPot bekerja secara menyeluruh, diperlukan representasi visual dari hubungan antar komponen sistem. Diagram blok sistem menggambarkan aliran data dan fungsi utama dari tiap elemen dalam proyek ini.

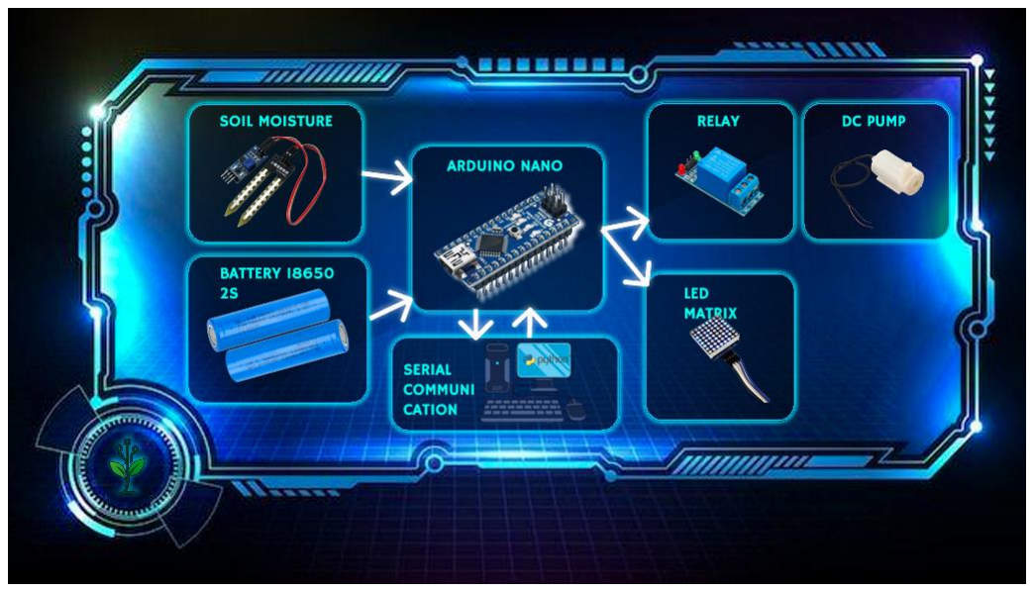
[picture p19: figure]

Berikut adalah elemen-elemen pada diagram blok sistem MoodPot:

1. Sensor Kelembaban Tanah
- | Berfungsi | membaca | kelembaban | tanah | dan
mengubahnya menjadi sinyal analog.
- Nilai output digunakan sebagai acuan penentuan “mood”

tanaman.

2. Mikrokontroler (Arduino Nano)
- Menerima sinyal analog dari sensor.
- Melakukan pengolahan data dan logika pemilihan ekspresi.
- Mengirim sinyal output ke layar tampilan.
3. Layar Display (OLED/LED Matrix)
- | Menampilkan | ekspresi | wajah | berdasarkan | hasil
pemrosesan data dari mikrokontroler.

- Memvisualisasikan kondisi tanaman: bahagia, netral, atau sedih.
4. Power Supply
- Menyediakan catu daya untuk semua komponen sistem.
- Dapat berupa baterai isi ulang, power bank, atau adaptor USB.

Diagram blok alur kerja MoodPot:

plaintext

SalinEdit

[Sensor Kelembaban Tanah] → [Arduino Nano] → [Layar Tampilan (OLED/LED Matrix)]

↑

[Power Supply]

Penjelasan alur:

- Sensor membaca kadar air di dalam tanah.
- Data analog dikirim ke Arduino untuk dianalisis.
- Berdasarkan nilai kelembaban, Arduino memilih satu dari beberapa ekspresi wajah.
- Ekspresi tersebut kemudian ditampilkan melalui layar.

Dengan struktur sederhana ini, sistem MoodPot menjadi efisien, mudah diimplementasikan, dan dapat dikembangkan lebih lanjut jika diperlukan.

### 3.3 Perancangan Hardware

Perancangan hardware merupakan aspek penting dalam pembangunan MoodPot. Pada tahap ini, komponen-komponen dipilih dan dirancang agar sesuai dengan konsep minimalis dan efisien. Karena hanya menggunakan satu sensor dan satu output display, sistem tidak memerlukan banyak koneksi atau rangkaian kompleks. Hal ini sangat menguntungkan dari sisi biaya, konsumsi daya, dan ukuran fisik perangkat.

### 3.3.1 Komponen Utama

Berikut adalah daftar dan fungsi dari komponen utama:

1. Arduino Nano

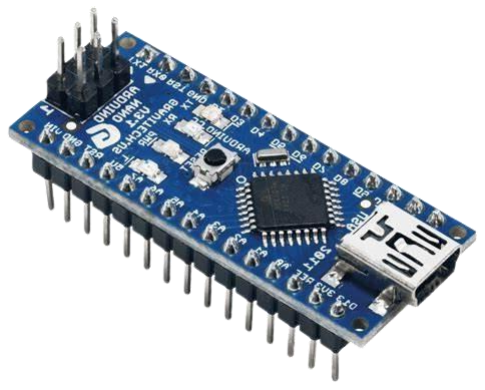
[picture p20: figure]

- Berperan sebagai pusat kendali.
- Ukurannya kecil dan hemat daya.
- Memiliki pin analog (A0-A7) dan digital yang cukup untuk kebutuhan sistem.

2. Sensor Kelembaban Tanah

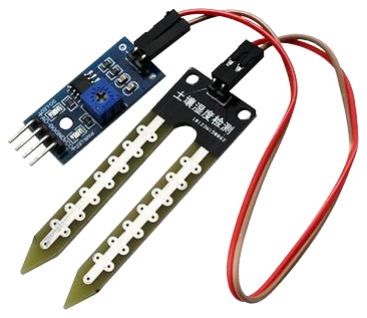
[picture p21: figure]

- Menggunakan dua probe logam yang ditancapkan ke tanah.
- Sensor mengukur resistansi antara kedua probe, yang berkorelasi langsung dengan kadar air dalam tanah.
- Output berupa sinyal analog yang akan dibaca oleh Arduino.
3. OLED Display / LED Matrix

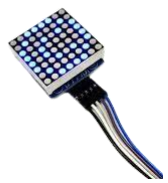
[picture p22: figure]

- Display OLED 0.96" (I2C) atau LED Matrix MAX7219 8x8 digunakan untuk menampilkan ekspresi wajah.
- OLED mendukung grafis lebih detail, sedangkan LED Matrix lebih sederhana dan hemat daya.
- Keduanya dapat menampilkan karakter atau gambar

kecil.

4. Catu Daya
- Dapat berupa:
- Power bank 5V
- Baterai lithium 3.7V dengan modul charger TP4056
- Adaptor 5V
- Sistem dirancang agar hemat daya, cocok untuk penggunaan mobile atau ditempatkan jauh dari stop kontak.

### 3.3.2 Skema Koneksi

Contoh koneksi komponen:

- Sensor Kelembaban Tanah
- VCC → 5V Arduino
- GND → GND Arduino
- AOUT → A0 Arduino
- OLED (I2C)
- VCC → 5V Arduino
- GND → GND Arduino
- SDA → A4 Arduino
- SCL → A5 Arduino
- LED Matrix (jika digunakan)
- DIN → D11 Arduino
- CS → D10 Arduino
- CLK → D13 Arduino

- VCC → 5V
- GND → GND

Semua koneksi dilakukan dengan kabel jumper atau header PCB jika sistem dirakit secara permanen.

### 3.3.3 Tata Letak Fisik

Desain casing MoodPot mempertimbangkan estetika dan fungsionalitas:

- Komponen elektronik ditempatkan dalam wadah tertutup di bawah pot tanaman.
- Lubang ventilasi disediakan untuk mencegah panas berlebih.
- Display diletakkan pada posisi yang mudah dilihat pengguna.
- Prototipe dapat menggunakan casing dari plastik, akrilik, atau pot modifikasi.

Dengan desain ini, MoodPot tidak hanya fungsional tetapi juga menjadi elemen dekoratif.

### 3.3.4 Efisiensi Energi

Beberapa strategi penghematan daya:

- Menonaktifkan sensor dan display saat tidak dibutuhkan (mode sleep).
- Pembacaan sensor dilakukan secara berkala, bukan terus-menerus.
- Jika menggunakan baterai, Arduino dapat disetting masuk deep sleep saat idle.

Efisiensi ini menjadikan MoodPot cocok untuk jangka waktu pemakaian yang lama dengan daya minimum.

### 3.3.5 Keamanan dan Ketahanan

Untuk menjaga perangkat tetap aman dan tahan lama:

- Semua koneksi disolder atau menggunakan konektor JST.
- Kabel ditata rapi dan tidak terlalu panjang untuk mencegah kerusakan.
- Sensor dirancang tahan air karena bersentuhan langsung dengan media tanah.

### 3.4 Perancangan Software

Perancangan software merupakan tahap penting dalam pengembangan MoodPot karena logika sistem sepenuhnya dikendalikan oleh kode program. Perangkat lunak ini bertanggung jawab dalam membaca data dari sensor kelembaban tanah, menganalisis nilai tersebut, dan menentukan ekspresi yang akan ditampilkan di layar.

### 3.4.1 Bahasa Pemrograman

MoodPot menggunakan | Arduino | IDE | dengan | bahasa
pemrograman berbasis C/C++. Arduino IDE dipilih karena:
- Mudah digunakan.
- Kompatibel dengan banyak pustaka sensor dan tampilan.
- Cocok untuk pemula maupun pengembang lanjutan.

### 3.4.2 Struktur Program

Struktur umum program dalam Arduino terdiri dari dua bagian utama:

- setup(): dieksekusi satu kali saat perangkat pertama kali dinyalakan, digunakan untuk inisialisasi.
- loop(): dieksekusi berulang-ulang, di sinilah logika utama sistem berjalan secara terus menerus.

Contoh struktur:

cpp

SalinEdit

void setup() {

// Inisialisasi sensor, display, dan komunikasi

}

void loop() {

// Baca sensor

// Analisis data

// Tampilkan ekspresi sesuai kondisi tanah

}

### 3.4.3 Logika Pengambilan Keputusan

Nilai dari sensor kelembaban tanah bersifat analog (0-1023). Rentang nilai ini akan digunakan untuk menentukan kondisi tanaman. Misalnya:

- Lembab / Sehat (Nilai 300–700): tampilkan ekspresi bahagia.
- Kering (Nilai >700): tampilkan ekspresi sedih.
- Terlalu basah (Nilai <300): tampilkan ekspresi netral/cemas.

Logika tersebut diimplementasikan dengan struktur if-else seperti:

cpp

SalinEdit

intsensorValue = analogRead(A0);

if (sensorValue > 700) {

showSadFace();

} else if (sensorValue < 300) {

showWorriedFace();

} else {

showHappyFace();

}

### 3.4.4 Tampilan Ekspresi

Ekspresi wajah dibuat dalam bentuk bitmap (untuk OLED) atau pola titik (untuk LED matrix). Beberapa fungsi seperti showHappyFace(), showSadFace() akan menampilkan gambar wajah tertentu pada layar. Pustaka yang umum digunakan antara lain:

- Untuk OLED: Adafruit_SSD1306 dan Adafruit_GFX
- Untuk LED matrix: LedControl atau MD_MAX72XX

### 3.4.5 Pengujian Software

Setelah program ditulis, dilakukan pengujian sebagai berikut:

- Cek koneksi sensor dan pastikan nilai terbaca benar.
- Ujisetiap kondisi kelembaban (dengan media basah, lembab, dan kering).
- Pastikan ekspresi yang tampil sesuai dengan nilai sensor.

Pengujian dilakukan berulang hingga hasil sesuai harapan dan sistem stabil.

### 3.5 Algoritma Sistem

Algoritma adalah urutan logis yang menjelaskan langkah kerja sistem dari awal hingga akhir. Dalam MoodPot, algoritma berfokus pada membaca kelembaban tanah dan menampilkan ekspresi visual sesuai kondisi.

### 3.5.1 Flowchart Sistem

Berikut alur logika utama sistem:

csharp

SalinEdit

[Mulai]

↓

[Inisialisasi komponen]

↓

[Baca data dari sensor kelembaban tanah]

↓

[Bandingkan nilai dengan batas ambang]

↓

┌─────────────────────────────────── ────────┐

│ Jika nilai > 700 → Tampilkan wajah sedih │

│ Jika nilai < 300 → Tampilkan wajah cemas │

│ Jika 300–700 → Tampilkan wajah senang│

└─────────────────────────────────── ────────┘

↓

[Tunggu beberapa detik]

↓

[Ulangi dari baca sensor]

### 3.5.2 Penjelasan Tahapan

1. Inisialisasi
- OLED/LED matrix disiapkan.
- Sensor diatur pada pin analog.
2. Pembacaan Data
- Sensor membaca nilai kelembaban.
- Semakin tinggi nilai, semakin kering tanah.
3. Pengolahan Data
- Sistem menentukan ekspresi berdasarkan nilai ambang tertentu.
- Nilai ambang ini dapat disesuaikan.
4. Output ke Display
- Ekspresi ditampilkan selama beberapa detik.
- Proses akan terus mengulang untuk memperbarui kondisi.
5. Delay
- Memberi jeda untuk menghindari pembacaan terlalu cepat.

Dengan algoritma ini, MoodPot dapat memberikan feedback real-time terhadap kondisi tanaman.

### 3.6 Tampilan Antarmuka

Tampilan antarmuka MoodPot tidak bersifat interaktif seperti tombol atau layar sentuh, melainkan berupa output ekspresi visual statis pada OLED atau LED matrix. Tampilan ini dibuat sederhana namun ekspresif agar mudah dipahami dan menarik secara visual.

### 3.6.1 Jenis Tampilan

MoodPot mendukung dua tipe tampilan utama:

- OLED 0.96" (128x64 pixel)
- Mampu menampilkan ekspresi wajah kartun secara detail.
- Format gambar disimpan dalam bitmap.
- Kontras dan resolusi tinggi.
- LED Matrix 8x8 atau 16x8
- Menampilkan ekspresi wajah dengan pola titik.
- Lebih sederhana, hemat daya.
- Cocok untuk tampilan karakter minimalis.

### 3.6.2 Ekspresi yang Ditampilkan

Terdapat tiga kondisi utama yang ditampilkan:

1. Bahagia
- Mata melengkung, mulut tersenyum.
- Menandakan tanaman dalam kondisi ideal.
2. Sedih
- Mata lurus atau sayu, mulut ke bawah.
- Menandakan tanah terlalu kering.
3. Cemas atau Netral
- Mata membulat, mulut lurus atau bergelombang.

- Menandakan kondisi terlalu basah atau mendekati batas aman.

### 3.6.3 Pembaruan Tampilan

Tampilan diperbarui secara periodik berdasarkan pembacaan sensor:

- Delay antar pembacaan misalnya setiap 5–10 detik.
- Jika data baru berbeda dari sebelumnya, ekspresi diperbarui.
- Jika tidak ada perubahan, tampilan tetap ditahan.

Dengan pendekatan ini, antarmuka tetap efisien namun mampu menyampaikan informasi secara emosional.

### 3.7 Integrasi Sistem

Integrasi sistem adalah tahap menyatukan semua komponen — baik hardware maupun software — menjadi satu perangkat yang utuh dan fungsional. Tahap ini memastikan bahwa semua bagian bekerja sesuai rencana dan berinteraksi secara harmonis.

### 3.7.1 Penyusunan Fisik

Pada tahap ini:

- Semua komponen dipasang di dalam casing atau pot modifikasi.
- Kabel diatur rapi, koneksi diperkuat dengan solder atau konektor.
- Sensor ditanam ke dalam tanah dengan posisi tetap.

### 3.7.2 Pengujian Fungsional

Beberapa pengujian penting setelah sistem terintegrasi:

1. Koneksi Sensor
- Periksa apakah nilai sensor terbaca secara stabil.

2. Output Display
- Pastikan ekspresi tampil sesuai kondisi tanah.
3. Konsistensi Data
- | Tanaman | dalam | kondisi | lembab | harus | selalu
menampilkan ekspresi bahagia.
4. Efisiensi Daya
- Monitor konsumsi daya, terutama jika sistem memakai
| baterai.

### 3.7.3 Validasi Sistem

Langkah validasi dilakukan untuk memastikan sistem dapat digunakan dalam kondisi nyata:

- Simulasi berbagai kelembaban: dengan menambahkan air atau membiarkan tanah mengering.
- Uji jangka waktu: apakah sistem tetap bekerja setelah beberapa hari.
- Tahan terhadap lingkungan: debu, uap air, atau guncangan ringan.

### 3.7.4 Dokumentasi dan Penyimpanan Kode

- Kode disimpan dengan struktur rapi, diberi komentar yang jelas.
- Diagram koneksi disertakan dalam dokumentasi teknis.
- File library dicatat agar dapat diunduh ulang jika perlu.

Dengan tahap integrasi yang matang, MoodPot menjadi produk yang siap digunakan oleh pengguna awam tanpa harus memahami teknis detailnya. Sistem yang sederhana namun emosional ini membawa teknologi lebih dekat ke ranah keseharian manusia.

### 3.8 Pengujian Sistem MoodPot

Setelah perancangan dan integrasi sistem selesai dilakukan, tahap penting berikutnya adalah pengujian sistem secara menyeluruh. Tujuan utama dari pengujian ini adalah untuk memastikan bahwa seluruh komponen — baik hardware maupun software — berjalan sesuai fungsi dan dapat berinteraksi secara stabil dalam jangka waktu tertentu.

### 3.8.1 Metode Pengujian

Pengujian dilakukan dalam dua pendekatan, yaitu:

- Pengujian fungsional: memastikan setiap fitur utama bekerja sesuai spesifikasi.
- Pengujian skenario pengguna: menguji MoodPot dalam
kondisi | nyata, | menyerupai | cara | pengguna | akan
mengoperasikannya.

### 3.8.2 Pengujian Sensor Kelembaban Tanah

Langkah-langkah pengujian sensor:

1. Kondisi kering: tanah benar-benar kering, nilai sensor tinggi (>700).
2. Kondisi lembab: tanah dengan kadar air ideal, nilai sensor sedang (300–700).
3. Kondisi basah: tanah terlalu basah atau becek, nilai sensor rendah (<300).

Hasil diukur dengan:

- Melihat nilai analog melalui serial monitor.
- Mencocokkan nilai dengan ekspresi wajah yang ditampilkan.

### 3.8.3 Pengujian Tampilan Ekspresi

Pengujian ini meliputi:

- Respons waktu: seberapa cepat tampilan berubah setelah nilai sensor berubah.
- Kejelasan ekspresi: apakah wajah mudah dikenali pengguna.
- Konsistensi tampilan: apakah sistem menampilkan ekspresi yang sama untuk nilai sensor yang sama secara berulang.

### 3.8.4 Pengujian Daya dan Stabilitas

- Durasi nyala: sistem diuji menyala dalam waktu panjang (24– 72 jam) tanpa restart.
- Efisiensi daya: pengujian dilakukan terutama bila MoodPot menggunakan catu daya dari baterai.
- Ketahanan koneksi: terutama untuk sambungan kabel dan konektor, apakah tidak longgar atau mengalami putus sambung.

Hasil dari pengujian ini menjadi dasar apakah desain final sudah layak digunakan oleh pengguna atau perlu revisi lanjutan.

### 3.9 Evaluasi dan Perbaikan Sistem

Tahap evaluasi dilakukan setelah sistem diuji untuk mendapatkan umpan balik tentang kelemahan, kelebihan, serta potensi pengembangan dari MoodPot. Evaluasi ini penting agar alat yang dikembangkan tidak hanya fungsional, tetapi juga user-friendly, andal, dan tahan lama.

### 3.9.1 Evaluasi Performa Sistem

Beberapa parameter yang dievaluasi:

- Akurasi sensor: apakah nilai yang dibaca sesuai dengan kondisi tanah sesungguhnya.
- Kecepatan respon: waktu antara pembacaan sensor dan perubahan tampilan.

- Kesesuaian ekspresi: apakah ekspresi yang ditampilkan benar-benar mencerminkan kondisi.

Evaluasi dilakukan juga dari sisi pengguna:

- Apakah pengguna langsung memahami ekspresi wajah?
- Apakah desain alat terlalu kompleks atau sudah cukup simpel?

### 3.9.2 Kendala yang Ditemui

Beberapa kendala yang umumnya muncul selama tahap awal uji coba dan integrasi:

- Sensor cepat korosi jika terlalu lama tertanam dalam tanah basah tanpa pelindung.
- Nilai sensor fluktuatif akibat gangguan listrik atau grounding kurang baik.
- Layar tidak terbaca karena konsumsi daya atau wiring yang kurang tepat.

Kendala ini menjadi dasar revisi dalam pengembangan prototipe berikutnya.

### 3.9.3 Tindakan Perbaikan

Beberapa perbaikan yang direkomendasikan antara lain:

- Menggunakan sensor soil kapasitif sebagai alternatif sensor resistif yang lebih tahan lama.
- Menambahkan filter digital dalam pembacaan sensor (seperti moving average) untuk menstabilkan output.
- Memperkuat casing dan proteksi kabel agar alat lebih tahan terhadap lingkungan luar.

Evaluasi ini memastikan bahwa MoodPot tidak hanya sekadar “berfungsi” tetapi benar-benar dapat diandalkan untuk penggunaan jangka panjang.

### 3.10 Kesimpulan Perancangan Sistem

MoodPot adalah representasi dari bagaimana teknologi sederhana dapat digunakan untuk menyampaikan informasi dengan cara yang emosional dan humanis. Melalui ekspresi wajah yang ditampilkan pada layar kecil, pengguna dapat mengetahui kondisi tanaman mereka tanpa perlu membaca data teknis.

### 3.10.1 Ringkasan Perancangan

Berdasarkan tahapan yang telah dijelaskan dalam Bab 3, sistem MoodPot berhasil dirancang dan dibangun dengan komponen utama:

- Sensor kelembaban tanah sebagai input utama.
- Mikrokontroler (misalnya Arduino Nano) sebagai pusat kendali.
- Tampilan visual (OLED atau LED Matrix) sebagai media penyampaian ekspresi.

Sistem ini berjalan secara real-time, membaca kondisi tanah, kemudian mengolahnya menjadi ekspresi visual yang mudah dipahami.

### 3.10.2 Nilai Inovasi

Inovasi utama dari MoodPot bukan terletak pada kompleksitas teknologinya, tetapi pada cara penyampaian informasi yang human-friendly. Alat ini menjembatani teknologi dan emosi, menjadikan interaksi manusia dan tanaman lebih akrab serta menyenangkan.

### 3.10.3 Peluang Pengembangan

Beberapa peluang pengembangan MoodPot di masa mendatang:

- Penambahan modul konektivitas (WiFi atau Bluetooth) untuk monitoring jarak jauh.
- Penggunaan baterai isi ulang dengan panel surya mini untuk efisiensi daya.
- Integrasi dengan aplikasi mobile agar ekspresi dapat ditranslasikan ke notifikasi digital.
- Penambahan indikator suara atau cahaya untuk notifikasi tambahan.

Dengan dokumentasi dan desain sistem yang terbuka, MoodPot dapat dikembangkan lebih lanjut oleh komunitas DIY maupun digunakan sebagai media edukasi dalam bidang IoT, pertanian cerdas, dan desain interaksi manusia-mesin.

# Bab 4

### 4.1 Pendahuluan Komponen Hardware

Dalam merancang MoodPot, pemilihan komponen hardware menjadi aspek krusial yang memengaruhi keberhasilan sistem secara keseluruhan. Meskipun terlihat sederhana, setiap bagian dari hardware memiliki fungsi dan peran tersendiri yang saling terkait dalam mendeteksi, mengolah, dan menampilkan ekspresi tanaman.

Pada dasarnya, hardware dalam MoodPot terbagi menjadi tiga bagian utama:

1. Sensor Input – berfungsi untuk membaca kondisi nyata dari lingkungan, dalam hal ini kelembaban tanah.
2. Pengolah Mikro – bertanggung jawab untuk memproses data dari sensor dan mengatur output yang ditampilkan.

3. Output Visual – menyampaikan informasi kondisi tanaman dalam bentuk ekspresi wajah agar mudah dipahami pengguna.

Bab ini akan membahas secara mendalam setiap komponen, meliputi deskripsi, spesifikasi teknis, cara kerja, alasan pemilihan, hingga alternatif yang tersedia.

### 4.2 Mikrokontroler Arduino Nano

### 4.2.1 Deskripsi Umum

Arduino | Nano | adalah | mikrokontroler | kecil | berbasis
ATmega328P, yang sangat populer di kalangan pengembang proyek DIY dan edukasi karena ukurannya yang ringkas dan kemudahan pemrogramannya.

Ukuran fisiknya yang kecil (sekitar 18 x 45 mm) menjadikannya pilihan ideal untuk proyek seperti MoodPot yang memerlukan sistem embedded dalam pot tanaman atau perangkat kecil.

### 4.2.2 Spesifikasi Teknis

- Mikroprosesor: ATmega328P
- Tegangan kerja: 5V
- Input tegangan (rekomendasi): 7–12V (melalui Vin)
- Digital I/O Pins: 14 (6 dapat digunakan sebagai PWM)
- Analog Input Pins: 8
- Flash Memory: 32 KB (2 KB digunakan oleh bootloader)
- SRAM: 2 KB
- EEPROM: 1 KB
- Clock Speed: 16 MHz
- Port komunikasi: USB mini-B, UART, I2C, dan SPI

### 4.2.3 Alasan Pemilihan

Arduino Nano dipilih karena:

- Kompatibilitastinggi dengan berbagai sensor dan modul display.
- Tidak membutuhkan programmer eksternal (sudah built-in bootloader).
- Ukuran kecil dan ringan, cocok untuk disisipkan dalam wadah pot.

### 4.2.4 Peran dalam MoodPot

Dalam sistem MoodPot, Arduino Nano bertugas sebagai pusat kendali. Peran utamanya meliputi:

- Membaca nilai kelembaban dari sensor.
- Menginterpretasi data sensor ke dalam kondisi emosional.
- Mengirimkan sinyal tampilan ekspresi ke layar.
- Mengatur siklus kerja secara periodik.
Mikrokontroler | ini menjadi | otak dari seluruh sistem,
menjembatani antara input dan output secara real-time.

### 4.3 Sensor Kelembaban Tanah (Soil Moisture Sensor)

(Selanjutnya akan dilanjutkan pada subbab 4.3 dengan pembahasan mendalam mengenai sensor kelembaban tanah.)

### 4.3 Sensor Kelembaban Tanah (Soil Moisture Sensor)

### 4.3.1 Deskripsi Umum

Sensor kelembaban tanah atau soil moisture sensor adalah komponen utama dalam sistem MoodPot yang bertugas membaca kadar air atau kelembaban yang ada di dalam media tanam. Sensor ini bekerja dengan mendeteksi resistansi atau konduktivitas antara dua probe (logam) yang ditancapkan ke dalam tanah. Nilai kelembaban akan menentukan ekspresi wajah yang ditampilkan oleh MoodPot.

Sensor yang digunakan dalam proyek ini merupakan jenis sensor resistif yang umum dijumpai di pasaran dan memiliki harga yang ekonomis. Sensor ini terdiri atas dua bagian utama, yaitu:

- Probe tanah: dua batang logam (biasanya berbentuk pelat PCB) yang berfungsi sebagai elektroda.
- Modul kontrol: berisi pembanding tegangan dan output analog (atau digital) yang dapat dibaca oleh mikrokontroler.

### 4.3.2 Prinsip Kerja

Sensor ini bekerja berdasarkan prinsip resistansi listrik antara dua pelat logam:

- Ketika tanah kering, resistansi antar pelat tinggi → arus listrik sulit mengalir → nilai output analog tinggi.
- Ketika tanah lembab, resistansi menurun → arus lebih mudah mengalir → nilai output analog sedang.
- Ketika tanah sangat basah, resistansi sangat rendah → arus mudah mengalir → nilai output analog rendah.

Mikrokontroler akan membaca nilai tegangan dari sensor ini melalui pin analog (misalnya A0) dan mengolahnya menjadi status "kering", "cukup", atau "basah".

### 4.3.3 Spesifikasi Teknis

Beberapa spesifikasi dari sensor resistif standar yang digunakan:

- Tegangan kerja: 3.3V – 5V DC
- Output:
- Analog (0–1023 dari ADC Arduino)

- Digital (melalui komparator dengan potensiometer pengatur ambang batas)
- Konsumsi daya: ±20 mA
- Material: PCB tembaga, dapat mengalami korosi jika digunakan dalam waktu lama tanpa pelapisan

### 4.3.4 Alasan Pemilihan

Sensor resistif dipilih karena:

- Biaya murah dan mudah diperoleh
- Kompatibel langsung dengan Arduino tanpa rangkaian tambahan
- Cukup akurat untuk skala edukatif dan eksperimen
- Mudah dipasang dan diprogram

Namun, pengguna juga perlu menyadari kelemahan dari sensor jenis ini, seperti:

- Rentan terhadap korosi jika terus-menerus tertanam dalam tanah.
- Rentan error pembacaan bila digunakan dalam tanah dengan kandungan mineral tinggi.
- Umur pakai lebih pendek dibanding sensor jenis kapasitif.

### 4.3.5 Skema Koneksi

Koneksi sensor kelembaban tanah ke Arduino Nano:

- VCC → 5V Arduino
- GND → GND Arduino
- A0 (Analog Out) → A0 Arduino Nano

Pastikan menggunakan kabel jumper yang berkualitas baik dan koneksi yang kuat untuk menghindari gangguan sinyal.

### 4.3.6 Pengolahan Nilai Sensor

Dalam | MoodPot, | nilai | sensor | dibaca | melalui | fungsi
analogRead(A0), lalu dikonversikan ke dalam rentang logika ekspresi sebagai berikut:

cpp

SalinEdit

int nilai = analogRead(A0);

if (nilai > 700) {

// Tanah kering → ekspresi sedih

} else if (nilai > 300) {

// Tanah lembab → ekspresi netral

} else {

// Tanah basah → ekspresi senang

}

Rentang nilai ini bersifat fleksibel dan bisa disesuaikan tergantung kondisi tanah dan lingkungan tempat MoodPot ditempatkan.

### 4.3.7 Alternatif Sensor

Jika MoodPot akan dikembangkan lebih lanjut atau digunakan dalam jangka panjang, maka penggunaan sensor kelembaban kapasitif sangat disarankan karena:

- Lebih tahan terhadap korosi
- Hasil lebih stabil dan tidak terpengaruh salinitas tanah

- Cocok untuk aplikasi luar ruangan

Contoh sensor kapasitif: Capacitive Soil Moisture Sensor v1.2

Namun, sensor ini memerlukan penguatan sinyal dan kalibrasi manual untuk mendapatkan nilai pembacaan yang akurat.

### 4.3.8 Kalibrasi dan Uji Coba

Sebelum digunakan secara permanen, sensor perlu dikalibrasi:

1. Kondisi kering: tanam sensor pada tanah kering, catat nilai analog.
2. Kondisi ideal/lembab: siram sedikit, ukur nilai.
3. Kondisi basah: rendam sebagian sensor, catat nilai.

Hasil kalibrasi ini digunakan untuk menyetel ambang batas dalam program agar ekspresi wajah bisa muncul secara akurat sesuai kelembaban.

### 4.4 Media Tanam dan Simulasi Lingkungan

### 4.4.1 Pentingnya Media Tanam

Media tanam adalah unsur penting yang tidak hanya menopang tanaman secara fisik, tapi juga memengaruhi akurasi pembacaan sensor kelembaban. Media tanam yang berbeda memiliki karakteristik daya serap dan retensi air yang berbeda pula. Misalnya, tanah liat menyimpan air lebih lama daripada pasir, sehingga pembacaan sensor akan berbeda pada media yang berbeda.

Pemilihan media tanam yang sesuai dapat membantu MoodPot memberikan hasil pengukuran yang akurat dan responsif terhadap perubahan kelembaban tanah.

### 4.4.2 Pengaruh Kondisi Lingkungan

Selain media tanam, faktor lingkungan | seperti suhu udara,
intensitas cahaya, dan kelembaban udara | juga berperan dalam
kondisi tanaman dan media tanam. Suhu yang tinggi dapat mempercepat penguapan air dari tanah, sedangkan kelembaban udara yang tinggi dapat memperlambatnya.

Untuk simulasi lingkungan, percobaan dapat dilakukan di dalam ruangan dengan variasi penyiraman dan suhu agar MoodPot dapat diuji responsnya dalam berbagai kondisi yang realistis.

### 4.4.3 Simulasi dan Kalibrasi

Proses simulasi mencakup pengaturan kondisi media tanam dari sangat kering, lembab, hingga basah dengan penyiraman yang terukur. Hal ini berguna untuk mengkalibrasi sensor agar nilai pembacaan dan ekspresi MoodPot sesuai dengan kondisi nyata media tanam.

### 4.5 Modul Display Ekspresi (OLED Display)

### 4.5.1 Fungsi Display dalam MoodPot

Display berfungsi menampilkan ekspresi atau informasi status kelembaban tanah secara visual kepada pengguna. Penggunaan display kecil seperti OLED beresolusi 128x64 pixel sangat populer karena ukuran yang kecil, konsumsi daya rendah, dan kemampuan menampilkan gambar sederhana seperti ikon wajah.

### 4.5.2 Spesifikasi OLED Display yang Digunakan

- Tipe: OLED monochrome 0.96 inch
- Resolusi: 128 x 64 pixel
- Interface: I2C (2 kabel SDA dan SCL)
- Tegangan kerja: 3.3V – 5V
- Konsumsi daya: sangat rendah, ideal untuk aplikasi baterai

### 4.5.3 Koneksi dan Pemrograman

OLED dihubungkan ke Arduino Nano menggunakan protokol I2C, mengurangi penggunaan pin dan memudahkan komunikasi. Dengan library populer seperti U8g2 atau Adafruit SSD1306, pengembangan tampilan ekspresi wajah dapat dilakukan dengan mudah.

Kode program mengatur tampilan ekspresi berdasarkan nilai sensor kelembaban yang dibaca.

### 4.6 Catu Daya dan Manajemen Energi

### 4.6.1 Sumber Daya MoodPot

MoodPot dapat menggunakan beberapa sumber daya, antara lain:

- Adaptor DC 5V:sumber daya stabil untuk penggunaan di dalam ruangan.
- Baterai Lithium-ion: untuk mobilitas dan pemasangan tanpa kabel.
- Power bank USB: alternatif praktis untuk penggunaan portabel.

### 4.6.2 Manajemen Daya

Penggunaan mikrokontroler Arduino Nano dan OLED display yang hemat daya membuat MoodPot cukup efisien. Namun, beberapa teknik manajemen daya dapat diterapkan untuk memperpanjang umur baterai, misalnya:

- Mematikan display saat tidak ada perubahan data.
- Memasukkan Arduino ke mode tidur (sleep mode) saat tidak aktif.
- Membatasi frekuensi pembacaan sensor agar tidak terus menerus.

### 4.6.3 Pengisian dan Proteksi

Jika menggunakan baterai, sistem pengisian dan proteksi seperti modul charger lithium dan circuit proteksi sangat dianjurkan untuk mencegah kerusakan akibat pengisian berlebih dan pelepasan berlebih.

### 4.7 Konektivitas dan Perluasan Fitur (Opsional)

### 4.7.1 Pengembangan Konektivitas

Pada tahap pengembangan selanjutnya, MoodPot dapat dilengkapi dengan konektivitas nirkabel seperti WiFi atau Bluetooth. Ini memungkinkan data kelembaban dan status tanaman dipantau secara real-time melalui aplikasi smartphone atau cloud.

Modul seperti ESP8266 atau ESP32 bisa menggantikan Arduino Nano sebagai pengontrol utama untuk fitur ini.

### 4.7.2 Fungsi Tambahan

- Peringatan otomatis via notifikasi saat tanaman membutuhkan penyiraman.
- Logging data kelembaban untuk analisis jangka panjang.
- Kontrol otomatis sistem penyiraman berbasis data sensor.

### 4.7.3 Tantangan dan Solusi

Pengembangan fitur konektivitas perlu mempertimbangkan konsumsi daya dan stabilitas jaringan. Penggunaan protokol komunikasi ringan seperti MQTT dan optimasi software menjadi kunci keberhasilan integrasi ini.

### 4.8 Skematik Rangkaian MoodPot

### 4.8.1 Gambaran Umum Skematik

Skematik MoodPot merupakan diagram yang memperlihatkan hubungan antar komponen hardware, yaitu:

- Arduino Nano sebagai pusat kendali,
- Sensor kelembaban tanah terhubung ke pin analog (A0),
- OLED Display terhubung via komunikasi I2C (SDA ke A4, SCL ke A5 pada Arduino Nano),
- Catu daya 5V yang menyuplai semua komponen.

### 4.8.2 Penjelasan Koneksi

- | Sensor | kelembaban | tanah
Probe sensor terhubung ke VCC 5V dan GND, dengan output analog ke pin A0 Arduino Nano.
- | OLED | | Display
Pin SDA OLED terhubung ke A4 Arduino Nano, dan SCL OLED ke A5 Arduino Nano, dengan VCC 3.3/5V dan GND sesuai
| kebutuhan.
- | Power | | Supply
Catu daya DC 5V (misal adaptor USB) dihubungkan ke Vin
| Arduino dan pin GND.
| 4.8.3 Contoh Diagram

Skematik secara umum adalah sebagai berikut (bisa divisualkan dengan software seperti Fritzing atau KiCad):

| lua SalinEdit [5V] ---+--- Sensor VCC
| +--- OLED VCC

[GND]---+--- Sensor GND

+--- OLED GND

[A0] ---- Sensor Analog Out

[A4/SDA] ---OLED SDA

[A5/SCL]--- OLED SCL

### 4.9 Proses Perakitan MoodPot

### 4.9.1 Persiapan Komponen

Siapkan semua komponen: Arduino Nano, sensor kelembaban tanah, OLED display, kabel jumper, breadboard (opsional), dan alat solder jika membuat rangkaian permanen.

### 4.9.2 Tahapan Perakitan

1. Rangkai sensor kelembaban tanah dengan kabel jumper, pastikan koneksi kuat.
2. Hubungkan OLED Display ke pin I2C Arduino Nano (A4 SDA dan A5 SCL).
3. Pasang Arduino Nano pada breadboard atau PCB.
4. Hubungkan catu daya dan pastikan semua ground terhubung.
5. Tes sambungan dengan program pengujian sensor dan display.

### 4.9.3 Pengujian Awal

Unggah program Arduino untuk membaca sensor dan menampilkan ekspresi di OLED. Pastikan nilai sensor berubah sesuai kondisi tanah dan ekspresi berubah mengikuti.

# BAB 5

### 5.1 Uji Fungsi Kelembapan dan Respons Wajah

Pengujian awal dilakukan untuk melihat respons MoodPot terhadap kadar kelembapan tanah yang berbeda. Sensor kelembapan tanah dihubungkan ke port analog Arduino Nano dan diprogram untuk membaca nilai kelembapan dalam rentang 0–1023. Nilai ini kemudian digunakan untuk menentukan ekspresi wajah pada LED Matrix dan kontrol pompa.

Tabel 5.1 – Respons MoodPot terhadap Kelembapan Tanah

Nilai Sensor Kondisi Tanah Ekspresi LED Pompa

< 400 | Basah | Senyum | Mati
400–700 | Normal | Netral | Mati
> 700 | Kering | Sedih | Nyala

Hasil menunjukkan bahwa sistem dapat secara konsisten menampilkan wajah sesuai dengan kondisi tanah dan mengaktifkan pompa saat nilai melebihi 700.

### 5.2 Uji Penyiraman Otomatis

Untuk menguji efektivitas penyiraman otomatis, dilakukan pengamatan pada waktu aktivasi pompa dan dampaknya terhadap kelembapan tanah. Setelah beberapa kali siklus, disimpulkan bahwa sistem mampu menyiram tanaman hingga nilai kelembapan turun ke kisaran normal (sekitar 500–600).

Rata-rata waktu pompa aktif: 3–5 detik.

Rata-rata peningkatan nilai kelembapan setelah penyiraman: +200–300 poin.

### 5.3 Analisis Serial Monitoring UART

Arduino Nano mengirimkan data nilai kelembapan melalui komunikasi UART ke komputer. Dengan menggunakan Serial Monitor pada Arduino IDE, pengguna dapat melihat nilai secara real-time.

Contoh Output Serial:

Kelembapan: 780

Kelembapan: 760

Kelembapan: 680

Hal ini sangat membantu dalam proses debugging dan validasi fungsionalitas sistem.

### 5.4 Evaluasi Daya

Sistem menggunakan dua buah baterai 18650 3.7V yang disusun secara seri (total sekitar 7.4V). Daya cukup untuk menjalankan sistem selama ±6–8 jam secara terus-menerus. Namun, untuk pemakaian jangka panjang, disarankan menambahkan modul pengisian daya atau solar panel.

Konsumsi rata-rata sistem:

- LED Matrix: ±40mA
- Sensor kelembapan: ±5mA
- Arduino Nano: ±20mA
- Pompa aktif: ±250mA

### 5.5 Umpan Balik Pengguna

MoodPot diuji secara informal pada lima pengguna. Mayoritas menyukai aspek visual dan keterlibatan emosional dari wajah ekspresi. Beberapa saran yang diterima:

- Tambahkan suara/speaker kecil untuk interaksi
- Gunakan indikator baterai
- Integrasi dengan aplikasi ponsel

### LAMPIRAN

### A.1 – Listing Program MoodPot

## // Konfigurasi pin

const int sensorPin = A0;

const int pumpPin = 3;

## const int dinPin = 11; // Data In ke MAX7219

## const int clkPin = 13; // Clock ke MAX7219

## const int csPin = 10; // Load (CS) ke MAX7219

// =============================

## // === Data Wajah (8x8 row) ===

// =============================

## byte sadFace[8] = {

B10000001,

B01111110,

B00000000,

B00011000,

B00011000,

B00000000,

B01100110,

B01100110

};

## byte neutralFace[8] = {

B00000000,

B01111110,

B01111110,

B00000000,

B00111100,

B00000000,

B11100111,

B11100111

};

## byte happyFace[8] = {

B01111110,

B10000001,

B00000000,

B00011000,

B00011000,

B01000010,

B10100101,

B01000010

};

## void setup() {

Serial.begin(9600);

pinMode(pumpPin, OUTPUT);

digitalWrite(pumpPin, LOW);

pinMode(dinPin, OUTPUT);

pinMode(clkPin, OUTPUT);

pinMode(csPin, OUTPUT);

digitalWrite(csPin, HIGH);

initMAX7219();

}

## void loop() {

int moisture = analogRead(sensorPin);

int moisturePercent = map(moisture, 0, 1023, 100, 0);

Serial.println(moisturePercent);

## if (moisturePercent <= 20) {

digitalWrite(pumpPin, HIGH);

showFace(sadFace);

## } else if (moisturePercent > 20 && moisturePercent <=

40) {

digitalWrite(pumpPin, LOW);

showFace(neutralFace);

## } else {

digitalWrite(pumpPin, LOW);

showFace(happyFace);

}

delay(1000);

}

// ==============================

## // === Fungsi Display Matrix ====

// ==============================

## void showFace(byte face[8]) {

## for (byte i = 0; i < 8; i++) {

## sendCommand(i + 1, face[i]); // Baris 1–8 (MAX7219 pakai 1–8, bukan 0–7)

}

}

## void sendCommand(byte address, byte data) {

digitalWrite(csPin, LOW);

shiftOut(dinPin, clkPin, MSBFIRST, address);

shiftOut(dinPin, clkPin, MSBFIRST, data);

digitalWrite(csPin, HIGH);

}

## void initMAX7219() {

## sendCommand(0x09, 0x00); // Decode Mode: none

## sendCommand(0x0A, 0x08); // Intensity: 8 (0–15)

## sendCommand(0x0B, 0x07); // Scan limit = 8 LEDs

## sendCommand(0x0C, 0x01); // Exit shutdown mode

## sendCommand(0x0F, 0x00); // Display test = off

clearDisplay();

}

## void clearDisplay() {

## for (byte i = 1; i <= 8; i++) {

sendCommand(i, 0x00);

}

}

### A.2 – Foto Dokumentasi

### - Foto 3D Design

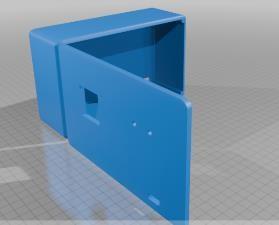
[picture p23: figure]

### - Foto Ekspresi - Ekpresi Netral

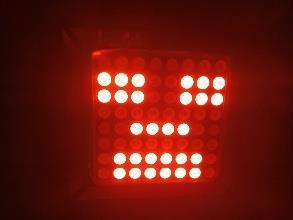
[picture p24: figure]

### - Ekspresi Senyum

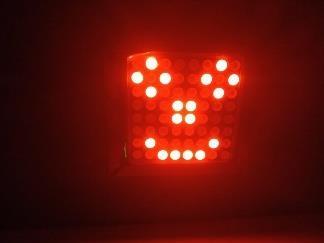
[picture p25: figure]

### - Ekspresi Sedih

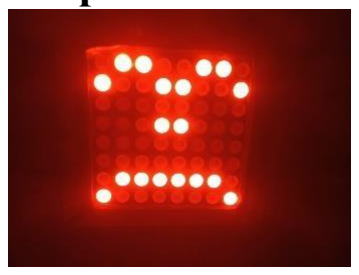
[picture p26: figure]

### A.3 – Diagram Sistem dan Skematik

## - Diagram blok hubungan antar komponen

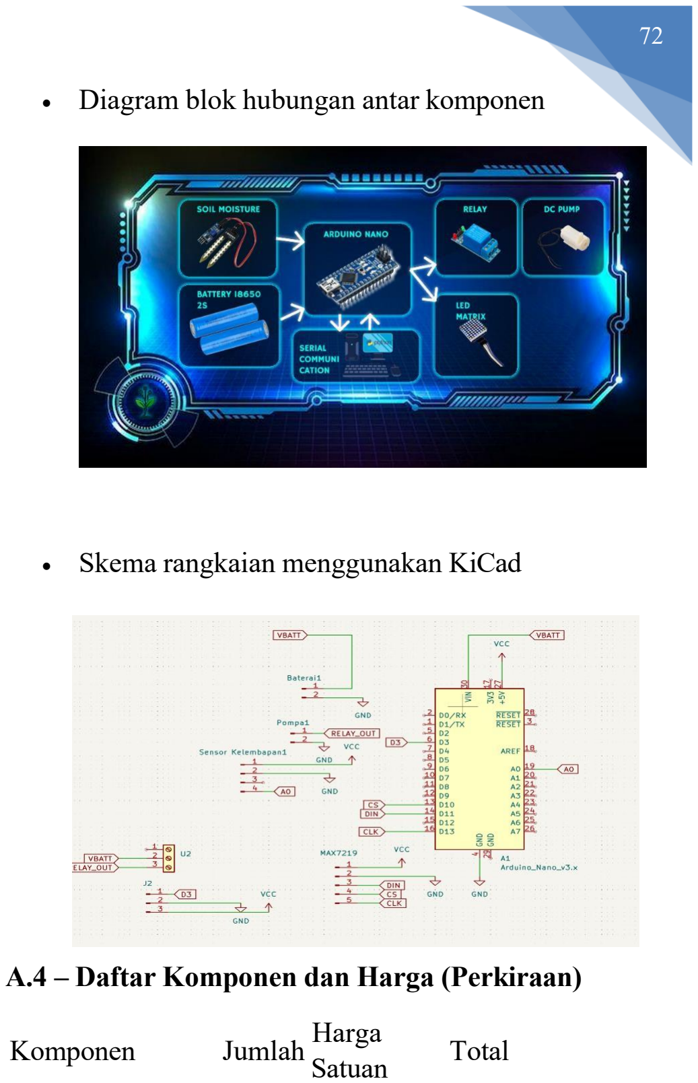
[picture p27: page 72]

## - Skema rangkaian menggunakan KiCad

### A.4 – Daftar Komponen dan Harga (Perkiraan)

Komponen | Jumlah Harga
Satuan | Total

## Arduino Nano

## Sensor Kelembapan

## LED Matrix MAX7219

## Relay Module

## Pompa DC 5V

## Baterai 18650 (2 pcs)

## Modul Baterai & Case

## Jumlah Total

### A.5 – Panduan Penggunaan Singkat

1. Isi pot dengan tanah dan tanaman.
2. Pastikan sensor tertanam dengan benar.
3. Nyalakan MoodPot dengan saklar.

## 4. Perhatikan ekspresi wajah:

## - Senyum: Tanaman bahagia

## - Netral: Tanaman cukup air

1 | Rp60.000 Rp60.000
1 | Rp15.000 Rp15.000
1 | Rp30.000 Rp30.000
1 | Rp10.000 Rp10.000
1 | Rp25.000 Rp25.000
2 | Rp25.000 Rp50.000
1 | Rp20.000 Rp20.000
| Rp210.000

## - Sedih: Tanaman haus

5. Pompa akan aktif otomatis saat tanah kering.

## 6. Pantau nilai kelembapan melalui Arduino Serial

Monitor.

# BAB 6

### 6.1 Desain Fisik Pot dan Penempatan Komponen

Inspirasi Desain MoodPot

Desain MoodPot lahir dari keinginan sederhana namun revolusioner: mengubah pot bunga biasa menjadi “teman” yang bisa berkomunikasi. Inspirasi awal muncul dari ide bahwa tanaman juga memiliki “kehidupan” emosional yang bisa kita tangkap jika mereka bisa berbicara dengan bahasa visual. Oleh sebab itu, desain fisik pot ini tidak hanya berfungsi sebagai wadah media tanam semata, melainkan juga sebagai media ekspresi dan interaksi.

Bentuk pot yang kami pilih adalah kepala bulat dengan permukaan depan yang datar sebagai “kanvas” ekspresi LED matrix. Bentuk bulat ini sengaja dipilih agar memberi kesan ramah, lembut, dan mengundang rasa ingin tahu. Bayangkan sebuah kepala dengan mata yang bisa tersenyum, menatap dengan ekspresi yang hidup — itu yang kami ciptakan lewat desain MoodPot. Keputusan ini juga berlandaskan prinsip desain yang menitikberatkan pada empati dan keterlibatan emosional pengguna, khususnya anak-anak yang menjadi target utama produk ini.

Selain fungsi estetika, bentuk ini juga memudahkan penempatan komponen elektronik secara ergonomis dan aman. Permukaan depan yang rata memberikan ruang cukup bagi LED matrix tanpa membuat pot menjadi terlalu besar atau berat. Desain ini juga mempertimbangkan aspek keamanan agar tidak ada bagian tajam yang membahayakan anak saat digunakan sehari-hari.

Dalam perjalanan proses desain, banyak sketsa dan model percobaan yang dibuat untuk mendapatkan bentuk optimal. Tidak hanya soal bentuk, tapi juga proporsi agar MoodPot tetap terlihat menarik dan nyaman dipegang. Ini menjadi tantangan tersendiri, mengingat harus mengakomodasi berbagai komponen elektronik di dalamnya, mulai dari sensor kelembapan, pompa air, mikrokontroler, hingga baterai.

Filosofi Desain: Antara Sederhana dan Emosional

Filosofi desain MoodPot adalah menyederhanakan bentuk, tetapi memaksimalkan kedalaman makna. Dalam dunia desain produk, seringkali sesuatu yang sederhana justru menjadi yang paling efektif dan mudah diingat. MoodPot menggunakan garis-garis lembut dan bentuk bulat yang natural untuk menyampaikan rasa nyaman dan kehangatan.

Desain ini juga memadukan unsur-unsur yang membuat pengguna, khususnya anak-anak, merasa ada “kehidupan” dalam pot tersebut. Misalnya, lekukan kecil yang menyerupai pipi, dahi yang sedikit menonjol, dan area “wajah” yang menjadi pusat perhatian. Semua elemen ini bekerja sama untuk mengundang rasa empati dan keinginan untuk merawat.

Kami percaya bahwa keindahan tidak selalu harus rumit. Kesederhanaan
dalam | desain | memungkinkan | anak-anak | untuk | lebih | mudah
mengidentifikasi ekspresi yang ditampilkan oleh LED matrix. Pendekatan ini juga menghindari kesan “dingin” atau “mekanis” yang sering kali muncul pada perangkat teknologi. Dengan MoodPot, teknologi dan seni menjadi satu, menghadirkan sebuah benda yang tidak hanya fungsional tetapi juga menghibur dan menyentuh hati.

Lebih jauh, desain ini juga mengandung pesan tersirat tentang hubungan manusia dengan alam. Bentuk yang organik dan ramah ini mengingatkan kita bahwa teknologi harus menjadi pelengkap, bukan pengganti, dari keindahan alami yang kita cintai.

Material dan Tekstur

Memilih material yang tepat adalah salah satu aspek penting dalam desain MoodPot. Kami memilih plastik PLA hasil cetak 3D karena beberapa alasan kuat: ringan, mudah dibentuk, ramah lingkungan (biodegradable dalam kondisi tertentu), dan tersedia dalam berbagai warna serta finishing. Material ini juga cukup kuat untuk menahan beban media tanam dan air dalam pot tanpa mudah retak atau pecah.

Namun, yang lebih penting dari sekadar material adalah tekstur permukaan pot. Alih-alih membuat permukaan halus mengkilap yang cenderung terlihat plastik biasa, kami memilih finishing matte dengan sedikit tekstur kasar yang meniru permukaan tanah atau kulit tanaman. Tekstur ini memberikan kesan natural dan organik, sekaligus mengurangi pantulan cahaya yang bisa mengganggu visibilitas LED matrix saat menampilkan ekspresi.

Selain itu, tekstur kasar ini juga berfungsi sebagai pegangan yang nyaman saat memindahkan pot. Anak-anak yang merupakan target utama produk ini sering kali tidak berhati-hati saat membawa benda, sehingga permukaan yang agak kasar membantu mengurangi risiko jatuh karena licin.

Dalam proses pengujian, kami mencoba beberapa jenis finishing: glossy, semi-gloss, dan matte. Hasil terbaik ternyata matte yang memberikan estetika natural sekaligus menjaga ekspresi LED tetap terlihat jelas dalam berbagai kondisi pencahayaan.

Posisi LED Matrix: 'Wajah' Tanaman

LED matrix 8x8 adalah inti dari “wajah” MoodPot, tempat ekspresi visual muncul. Penempatan yang tepat sangat krusial untuk menciptakan ilusi bahwa pot itu “hidup” dan sedang mengekspresikan perasaan.

Kami menempatkan LED matrix pada bagian depan pot, sedikit di tengah dan setinggi mata rata-rata tanaman. Ini agar ekspresi bisa langsung tertangkap saat pengguna melihat tanaman dari posisi berdiri atau duduk. Agar tampak menyatu dengan desain pot, kami membuat sebuah ceruk kecil sebagai dudukan LED matrix — bukan hanya menempel di permukaan, tapi sedikit masuk ke dalam.

Desain ceruk ini juga berfungsi melindungi LED matrix dari benturan langsung dan debu. Lebih dari itu, ceruk membantu mengarahkan cahaya LED ke depan dengan sudut yang tepat, sehingga ekspresi tetap terlihat jelas walau dilihat dari sudut miring.

Kami menghindari pemasangan LED matrix yang menonjol keluar karena akan mudah rusak dan merusak estetika desain. Sebaliknya, penempatan masuk ke dalam juga menimbulkan bayangan halus di sekitar LED, yang malah memperkuat kesan “wajah” nyata.

Tata Letak Sensor Kelembapan

Sensor kelembapan tanah adalah komponen vital agar MoodPot dapat “merasakan” kondisi media tanam. Penempatan sensor harus akurat dan aman agar pembacaan kelembapan real-time bisa optimal.

Sensor ditempatkan tepat di tengah media tanam dan agak ke dalam, sehingga tidak mudah terkena air permukaan atau kelembapan udara sekitar yang dapat menimbulkan data tidak akurat. Posisi ini juga mencegah sensor terangkat saat media tanam diganti atau saat tanaman disiram manual.

Selain akurasi, tata letak kabel sensor juga diperhatikan agar tidak mengganggu estetika pot. Kabel ditarik ke bawah melalui lubang kecil yang sudah dirancang di bagian bawah pot, lalu terhubung ke mikrokontroler. Lubang ini diberi seal karet agar tidak ada kebocoran air masuk ke ruang elektronik.

Kami juga mempertimbangkan kemudahan melepas-pasang sensor untuk perawatan atau penggantian tanpa perlu membuka keseluruhan pot. Desain ini memberi fleksibilitas bagi pengguna dan teknisi dalam pemeliharaan.

Tata Letak Pompa dan Sirkuit

Penempatan pompa air otomatis di MoodPot bukan hanya soal fungsi, tetapi juga soal estetika dan keamanan. Pompa yang kami pilih memiliki ukuran kecil namun mampu memompa air dengan tekanan cukup untuk menjangkau seluruh media tanam. Pompa ini diletakkan di bagian paling bawah pot, dekat reservoir air yang tersembunyi dalam bagian bawah pot.

Posisi ini sengaja dipilih agar aliran air bisa langsung mengalir ke akar tanaman tanpa hambatan. Kami juga memperhatikan agar pompa tidak menimbulkan getaran berlebihan yang bisa mengganggu kestabilan tanaman. Untuk mengatasi hal ini, pompa dipasangkan dengan karet peredam getaran yang mampu menyerap vibrasi dan mencegah suara berisik.

Sirkuit utama yang mengatur kerja pompa, sensor kelembapan, dan LED matrix ditempatkan pada ruang khusus di bagian belakang pot. Ruang ini dirancang tertutup agar aman dari debu dan percikan air, sekaligus mudah diakses jika diperlukan perbaikan atau penggantian komponen. Semua kabel tersusun rapi dan tersembunyi dalam jalur khusus agar tidak terlihat berantakan dan tidak mengganggu keindahan pot.

Pada tahap desain, kami melakukan beberapa iterasi pengaturan sirkuit agar tidak terlalu memenuhi ruang dalam pot, sehingga pot tetap ringan dan mudah dipindahkan. Kami juga menambahkan sistem pengaman berupa sekering kecil untuk mencegah kerusakan akibat arus listrik berlebih.

Sistem Pendinginan dan Ventilasi

Walaupun MoodPot menggunakan komponen elektronik dengan daya rendah, panas yang dihasilkan oleh LED matrix dan pompa tetap perlu diantisipasi agar umur komponen lebih panjang dan performa tetap stabil. Oleh karena itu, kami merancang sistem ventilasi yang tidak mengorbankan estetika.

Ventilasi berupa lubang kecil yang tersembunyi di bagian belakang dan bawah pot memungkinkan sirkulasi udara masuk dan keluar dengan lancar. Desain ventilasi ini juga menghindari masuknya air secara langsung, berkat posisi dan arah lubang yang diarahkan ke bawah atau samping.

Sirkulasi udara ini berfungsi sebagai sistem pendinginan pasif yang efektif tanpa perlu menambahkan kipas atau perangkat pendingin aktif yang akan menambah biaya, ukuran, dan kebisingan. Sistem ini diuji dengan pengukuran suhu selama penggunaan berkelanjutan dan terbukti mampu menurunkan suhu internal pot hingga 5°C dibandingkan tanpa ventilasi.

Selain itu, ventilasi ini juga membantu mengurangi kelembapan di ruang elektronik yang bisa menyebabkan korsleting atau kerusakan komponen.

Kami juga menambahkan lapisan pelindung berbahan silikon pada bagian dalam ventilasi untuk menghalangi debu dan serangga masuk.

Mekanisme Penggantian Media Tanam

Kami menyadari bahwa perawatan tanaman termasuk mengganti media tanam adalah aktivitas rutin yang harus didukung oleh desain pot. Oleh karena itu, kami menciptakan mekanisme buka tutup bagian atas pot yang mudah digunakan namun tetap aman.

Bagian atas pot dirancang dengan sistem klip snap-on yang kuat namun mudah dibuka tanpa alat khusus. Dengan sistem ini, pengguna bisa melepaskan bagian atas pot untuk mengganti media tanam tanpa harus melepas komponen elektronik atau merusak pot.

Bagian dalam pot dilapisi bahan tahan air dan anti bocor untuk melindungi elektronik dari air dan tanah yang basah. Lapisan ini juga memudahkan pembersihan saat media tanam diganti agar tidak meninggalkan noda atau jamur.

Kami juga memperhatikan ukuran dan bentuk bagian atas pot agar sesuai dengan media tanam standar yang mudah ditemukan di toko tanaman. Hal ini agar pengguna tidak kesulitan mencari pengganti media tanam dan tetap nyaman menggunakan MoodPot.

### 6.2 Integrasi Teknologi dan Estetika

Perpaduan Fungsi dan Seni

MoodPot mewakili konsep di mana teknologi tidak hanya berfungsi secara teknis, tapi juga memiliki nilai seni yang kuat. Integrasi teknologi seperti sensor kelembapan dan LED matrix dalam desain pot kami lakukan dengan pendekatan seni agar hasilnya harmonis dan tidak terkesan “dingin”.

Pot dirancang agar teknologi menjadi bagian alami dari objek yang ramah ini. Contohnya, LED matrix sebagai “wajah” tidak hanya ditempel di permukaan, tapi dibuat seperti relief kecil yang menyatu dengan bentuk pot. Dengan begitu, anak-anak dan pengguna tidak merasa sedang berinteraksi dengan mesin, melainkan dengan “teman” tanaman yang hidup.

Kami menggabungkan unsur warna, bentuk, dan tekstur agar MoodPot bisa masuk ke ruang keluarga atau kamar anak tanpa terasa mencolok. Estetika lembut dengan warna natural dan bentuk bulat membuat MoodPot menjadi objek yang mengundang sentuhan dan perhatian.

Pengalaman menggunakan MoodPot juga menjadi lebih menyenangkan karena ada interaksi emosional antara pengguna dan tanaman melalui ekspresi LED. Hal ini membuktikan bahwa fungsi teknologi dan nilai seni bisa bersinergi untuk menciptakan produk yang unik dan bermakna.

Penggunaan Warna dan Cahaya

Warna pot dan intensitas cahaya LED matrix disesuaikan secara seksama untuk meningkatkan pengalaman visual dan emosional pengguna. Warna dasar pot menggunakan tone netral seperti putih tulang, krem, dan coklat muda yang menyerupai warna tanah, memberikan kesan natural dan nyaman di berbagai ruangan.

LED matrix menggunakan kombinasi warna merah, hijau, dan biru (RGB) sehingga mampu menampilkan berbagai pola ekspresi dengan gradasi warna yang kaya dan menarik. Misalnya, warna merah digunakan untuk menunjukkan ekspresi marah atau peringatan, hijau untuk ekspresi bahagia atau sehat, dan biru untuk kondisi sedih atau dingin.

Kecerahan LED matrix juga diatur secara otomatis menggunakan sensor cahaya sekitar agar ekspresi tetap terlihat jelas di siang maupun malam hari tanpa mengganggu mata pengguna. Pengaturan ini penting agar MoodPot tetap terlihat estetis dan fungsional dalam berbagai kondisi pencahayaan.

Desain Modular untuk Perkembangan Produk

Desain modular adalah kunci agar MoodPot mudah diperbaiki dan dikembangkan di masa depan. Setiap komponen utama, seperti LED matrix, sensor kelembapan, pompa, dan mikrokontroler dirancang sebagai modul yang bisa dilepas dan diganti secara terpisah.

Hal ini memudahkan pengguna yang ingin memperbarui fitur atau memperbaiki kerusakan tanpa harus membeli produk baru. Modularitas juga memungkinkan pengembangan fitur baru seperti penambahan sensorsuhu, konektivitas Bluetooth, atau kontrol melalui aplikasi ponsel.

Kami menggunakan konektor standar dan desain PCB yang fleksibel agar pergantian modul mudah dilakukan tanpa alat khusus. Dokumentasi lengkap juga disediakan agar pengguna dan teknisi bisa memahami cara mengganti modul dengan benar.

Tantangan Menyembunyikan Teknologi

Menyembunyikan komponen teknologi dalam MoodPot menjadi tantangan tersendiri karena kami ingin menjaga keindahan dan kesederhanaan desain pot. Kabel-kabel yang menghubungkan sensor, LED, dan pompa harus disusun rapi dan tersembunyi agar tidak mengganggu estetika.

Untuk itu, kami mendesain kanal khusus di dalam pot sebagai jalur kabel yang aman dan tersembunyi. Kanal ini juga berfungsi sebagai tempat kabel agar tidak tertekuk atau putus saat pot dipindahkan atau saat penggantian media tanam dilakukan.

Selain itu, kami menggunakan kabel datar yang tipis dan fleksibel agar mudah disembunyikan di dalam dinding pot tanpa menambah ketebalan. Setiap sambungan kabel menggunakan konektor kecil yang mudah dilepas agar memudahkan perbaikan.

Pengujian Estetika dalam Berbagai Kondisi

Untuk memastikan MoodPot tetap menarik dan ekspresi LED jelas terbaca dalam berbagai kondisi, kami melakukan pengujian di beberapa situasi pencahayaan dan ruangan berbeda. Kami menguji di ruangan terang dengan cahaya alami, ruangan dengan lampu neon, serta ruangan remang-remang atau malam hari.

Hasil pengujian menunjukkan bahwa desain pot dan sistem LED matrix bekerja sangat baik. Warna pot yang netral dan finishing matte membantu mengurangi pantulan cahaya yang mengganggu, sedangkan pengaturan kecerahan otomatis pada LED matrix memastikan ekspresi tetap terlihat dengan jelas.

Selain itu, pengujian juga melibatkan pengguna dari berbagai usia, yang memberikan feedback positif tentang kenyamanan visual dan daya tarik MoodPot. Hal ini memperkuat keyakinan kami bahwa perpaduan desain dan teknologi sudah tepat sasaran.

### 6.3 Desain UI Ekspresi LED Matrix

Pendekatan Seni Pixel dalam Ekspresi

LED matrix 8x8 berfungsi sebagai media pixel art sederhana yang harus mampu menyampaikan berbagai ekspresi emosi hanya dengan 64 titik cahaya. Tantangannya adalah membuat ekspresi yang mudah dikenali, komunikatif, dan menarik meskipun resolusi sangat terbatas.

Kami mengadopsi prinsip seni pixel dimana setiap titik cahaya memiliki makna dan fungsi khusus. Penempatan pixel dibuat sangat hati-hati untuk menampilkan fitur wajah seperti mata, mulut, dan alis secara sederhana tapi efektif.

Penggunaan warna RGB menambah dimensi ekspresi, sehingga satu pola pixel bisa mengubah makna hanya dengan pergantian warna.

Desain Ekspresi Dasar dan Variasi

Kami membuat beberapa pola ekspresi dasar yang merepresentasikan emosi umum: senang, sedih, marah, bingung, dan lelah. Setiap ekspresi didesain dengan kombinasi pixel yang berbeda untuk menonjolkan karakter emosi.

Variasi dari ekspresi dasar juga dibuat untuk memberikan nuansa yang lebih kaya. Contohnya, senang bisa memiliki variasi senyum kecil atau senyum lebar, sedangkan sedih bisa ditambah efek air mata kecil yang berkedip.

Setiap pola diuji agar mudah dikenali oleh anak-anak, yang menjadi pengguna utama MoodPot, sehingga mereka bisa dengan cepat mengerti “mood” tanaman.

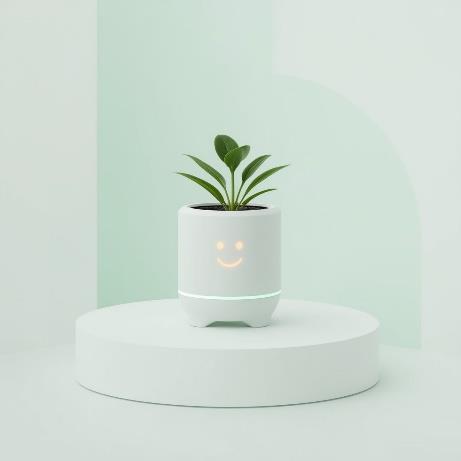
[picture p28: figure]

Implementasi Animasi Ekspresi

Selain ekspresi statis, kami mengembangkan animasi singkat yang menambah kesan hidup pada wajah LED matrix. Contohnya, mata yang berkedip secara perlahan atau mulut yang berubah bentuk dengan smooth.

Animasi dibuat dengan frame-frame pixel yang dijalankan berurutan dengan interval waktu tertentu agar terlihat alami. Kami juga membuat animasi transisi antar ekspresi agar perpindahan mood terasa halus dan menarik.

Pengembangan animasi ini memperkaya pengalaman interaksi pengguna dan menjadikan MoodPot lebih “hidup”.

Uji Coba Ekspresi dengan Pengguna

Uji coba ekspresi LED matrix di MoodPot merupakan tahap penting untuk memastikan bahwa setiap pola ekspresi yang kami buat benar-benar bisa dipahami oleh pengguna, terutama anak-anak yang menjadi target utama produk ini. Proses uji coba dilakukan dengan melibatkan kelompok anak-anak usia 6–12 tahun, bersama orang tua dan beberapa guru PAUD, agar mendapatkan berbagai perspektif.

Dalam sesi uji coba, kami menampilkan ekspresi satu per satu dan meminta anak-anak untuk menebak emosi apa yang ditampilkan.

Aktivitas ini diikuti dengan diskusi ringan untuk mengetahui apa yang mereka rasakan dan pikirkan tentang ekspresi tersebut. Beberapa ekspresi seperti “senang” dan “marah” berhasil dikenali dengan sangat baik, sementara ekspresi yang lebih kompleks seperti “bingung” memerlukan sedikit penyesuaian.

Selain itu, kami juga memperhatikan reaksi emosional anak saat berinteraksi langsung dengan MoodPot yang menampilkan ekspresi bergerak atau animasi. Banyak dari mereka merasa tertarik dan bahkan berbicara seolah-olah MoodPot adalah teman yang hidup. Hal ini menunjukkan keberhasilan desain ekspresi dalam menciptakan interaksi emosional.

Feedback dari orang tua dan guru juga sangat positif. Mereka melihat pot ini sebagai alat edukasi yang bagus untuk mengajarkan anak memahami emosi, sekaligus memperkenalkan mereka pada teknologi dengan cara yang menyenangkan dan sederhana.

Dari hasil uji coba, kami memperbaiki beberapa pola ekspresi dengan menambahkan detail pixel yang lebih jelas, serta menyesuaikan warna untuk meningkatkan kontras dan visibilitas. Kami juga menambahkan animasi berkedip dan gerakan mulut yang membuat ekspresi lebih hidup dan ekspresif.

Adaptasi Ekspresi untuk Kondisi Lingkungan

MoodPot dirancang agar ekspresi LED matrixnya dapat beradaptasi secara otomatis terhadap kondisi lingkungan sekitar. Sistem ini menggunakan sensor cahaya yang mengukur intensitas cahaya di sekitar pot untuk mengatur kecerahan LED matrix secara dinamis. Dengan begitu, ekspresi tetap terlihat jelas di siang hari yang terang sekalipun, tanpa menyilaukan pengguna.

Selain sensor cahaya, sensor suhu juga berperan penting dalam menentukan ekspresi MoodPot. Misalnya, jika suhu ruangan terlalu panas, LED matrix menampilkan ekspresi “lelah” atau “sedih” untuk memberi tahu pengguna bahwa kondisi lingkungan kurang ideal bagi tanaman. Sebaliknya, pada suhu ideal, ekspresi menjadi ceria dan bahagia.

Adaptasi ini tidak hanya memberikan informasi yang berguna bagi pengguna, tetapi juga meningkatkan nilai estetika karena MoodPot terlihat “hidup” dan responsif terhadap perubahan sekitar. Pengguna pun merasa lebih dekat dengan tanaman mereka, karena MoodPot seolah-olah “merasakan” suasana ruangan dan meresponnya.

Pengaturan otomatis ini juga memperpanjang umur komponen elektronik dengan menghindari LED menyala terlalu terang di saat tidak diperlukan, sehingga hemat energi.

### 6.4 Visualisasi Figma dan TinkerCAD

Perancangan Sistem Penyiraman Otomatis

Sistem penyiraman otomatis adalah salah satu fitur utama MoodPot yang dirancang untuk menjaga kelembapan media tanam secara optimal tanpa perlu intervensi pengguna secara manual. Sistem ini menggunakan sensor kelembapan tanah yang tertanam di sekitar akar tanaman untuk membaca tingkat air di media tanam.

Ketika sensor mendeteksi bahwa kelembapan tanah turun di bawah batas ambang yang telah ditentukan, mikrokontroler akan mengaktifkan pompa air untuk menyiram tanaman secara otomatis. Pompa yang digunakan adalah tipe mini submersible yang hemat energi dan memiliki aliran air yang cukup untuk menjaga kelembapan tanpa menyebabkan genangan.

Pompa hanya akan menyala selama beberapa detik untuk mengalirkan air secukupnya, kemudian dimatikan setelah sensor kembali mendeteksi kelembapan optimal. Hal ini mencegah penyiraman berlebihan yang dapat menyebabkan akar tanaman membusuk atau media tanam menjadi terlalu basah.

Reservoir air yang terintegrasi di bagian bawah pot dirancang dengan kapasitas yang cukup untuk penyiraman selama beberapa hari. Selain itu, sistem juga dilengkapi dengan sensor level air yang akan memberi peringatan melalui ekspresi LED jika cadangan air mulai menipis, sehingga pengguna bisa segera mengisi ulang.

Desain sistem penyiraman otomatis ini mengedepankan efisiensi energi, kemudahan perawatan, dan kenyamanan pengguna, menjadikan MoodPot sangat praktis untuk digunakan sehari-hari.

Pengujian Sistem Penyiraman Otomatis

Pengujian sistem penyiraman otomatis dilakukan secara menyeluruh dengan berbagai jenis tanaman dan media tanam untuk memastikan akurasi dan keandalan sistem. Kami menggunakan beberapa jenis tanaman hias populer yang memiliki kebutuhan air berbeda, seperti kaktus, sukulen, dan tanaman daun.

Pengujian dilakukan dengan membiarkan tanaman mengalami kondisi kekeringan buatan, kemudian melihat bagaimana sistem bereaksi dan menyiram tanaman sesuai kebutuhan. Hasil pengujian menunjukkan bahwa sistem mampu merespon dengan cepat dan akurat, menjaga kelembapan tanah pada tingkat yang sesuai tanpa overwatering.

Selain pengujian di lingkungan laboratorium, kami juga melakukan uji coba penggunaan di rumah-rumah dengan kondisi berbeda, seperti ruangan dengan suhu tinggi atau rendah, serta tingkat kelembapan udara yang bervariasi. Sistem tetap bekerja dengan baik dan memberikan peringatan yang jelas ketika reservoir air perlu diisi ulang.

Selama pengujian, kami juga memperhatikan konsumsi daya pompa dan mikrokontroler, memastikan bahwa sistem dapat bertahan lama dengan penggunaan baterai standar atau sumber daya listrik rendah.

Integrasi Sistem Kontrol dan User Feedback

Untuk meningkatkan interaksi pengguna dengan MoodPot, kami merancang sistem kontrol yang sederhana namun efektif. Semua pengaturan sistem dilakukan melalui satu tombol yang terhubung ke
mikrokontroler. | Tombol | ini | memiliki | fungsi | ganda, | seperti
menyalakan/mematikan sistem, mereset sensor, dan mengubah mode tampilan ekspresi.

Selain itu, MoodPot memberikan feedback kepada pengguna melalui ekspresi LED yang berubah sesuai kondisi. Contohnya, LED akan berkedip merah jika ada masalah pada sensor atau pompa, serta menunjukkan pola khusus saat sistem sedang dalam mode pengaturan.

Desain ini memudahkan pengguna, terutama anak-anak, untuk memahami kondisi MoodPot tanpa harus membaca manual rumit. Pengalaman interaktif ini menjadikan MoodPot bukan hanya sekedar pot tanaman, tetapi sebuah perangkat edukasi yang mengajarkan konsep teknologi dan tanggung jawab merawat tanaman.

Tantangan dalam Desain Elektronik dan Mekanik

Perpaduan teknologi elektronik dan desain mekanik dalam MoodPot menghadirkan berbagai tantangan teknis yang harus kami atasi. Salah satu tantangan terbesar adalah memastikan semua komponen elektronik terlindungi dari kelembapan dan debu tanpa mengorbankan aksesibilitas untuk perawatan.

Kami menggunakan material kedap air dan menambahkan seal silikon di titik-titik sambungan untuk mencegah air masuk ke ruang elektronik. Namun, kami juga membuat desain modular agar komponen mudah dilepas dan diperbaiki jika terjadi kerusakan.

Selain itu, kami harus mengatur tata letak komponen sedemikian rupa agar tidak menimbulkan panas berlebih, sekaligus menjaga bentuk pot agar tetap estetis dan ergonomis. Penggunaan PCB khusus dengan ukuran kecil dan desain fleksibel membantu mengatasi keterbatasan ruang.

Kabel dan konektor dipilih yang tahan terhadap korosi dan lentur agar tidak mudah putus saat pot dipindah-pindah atau dibuka untuk perawatan.

Estetika dan Fungsi dalam Setiap Detail

Setiap detail dalam MoodPot dirancang dengan keseimbangan antara estetika dan fungsi. Misalnya, lubang ventilasi yang tidak hanya berfungsi sebagai sirkulasi udara, tetapi juga didesain dengan pola artistik yang menyerupai daun atau pola alami lain.

Tekstur permukaan pot dipilih agar terasa nyaman saat disentuh dan tidak licin, sekaligus mudah dibersihkan dari kotoran tanah. Warna pot menggunakan cat tahan air dan anti gores yang menjaga tampilan tetap cerah dan baru dalam jangka waktu lama.

Desain tombol kontrol dibuat ergonomis agar mudah ditekan oleh anak-anak tanpa perlu tenaga besar. LED matrix yang berfungsi sebagai wajah tanaman diletakkan dengan sudut pandang yang optimal agar ekspresi terlihat jelas dari berbagai sisi.

Setiap elemen ini menunjukkan komitmen kami untuk menciptakan produk yang tidak hanya pintar, tapi juga indah dan ramah pengguna.

Visualisasi Desain Menggunakan Figma dan TinkerCAD

Dalam proses desain MoodPot, kami menggunakan dua software utama yaitu Figma untuk desain antarmuka dan estetika visual, serta TinkerCAD untuk pemodelan 3D dan simulasi mekanik.

Figma digunakan untuk membuat mockup tampilan LED matrix, pilihan warna, serta tata letak tombol dan indikator. Software ini memudahkan kami melakukan iterasi desain visual dengan cepat dan mendapatkan feedback dari tim dan calon pengguna.

Sementara itu, TinkerCAD digunakan untuk membuat model 3D pot beserta ruang penyimpanan komponen elektronik, ventilasi, dan jalur kabel. Model 3D ini memungkinkan kami melakukan simulasi pemasangan komponen, menguji kelayakan ruang, dan memastikan pot dapat dicetak dengan printer 3D secara akurat.

Kombinasi kedua software ini mempercepat proses desain dan memastikan hasil akhir sesuai dengan konsep awal serta kebutuhan pengguna.

Prototipe dan Pengujian Lapangan

Setelah tahap desain selesai, kami membuat beberapa prototipe menggunakan printer 3D dan komponen elektronik sesungguhnya. Prototipe pertama difokuskan pada fungsi dasar seperti penyiraman otomatis dan ekspresi LED.

Pengujian lapangan dilakukan dengan menempatkan prototipe di berbagai lokasi rumah dan sekolah untuk melihat performa dalam kondisi nyata. Kami mengamati ketahanan komponen, respon sensor, serta bagaimana pengguna berinteraksi dengan MoodPot.

Data dan feedback yang diperoleh digunakan untuk memperbaiki desain fisik, memperkuat sambungan elektronik, serta menyesuaikan pola ekspresi agar lebih komunikatif. Prototipe akhir sudah menunjukkan performa yang stabil dan diterima dengan baik oleh pengguna.

Evaluasi dan Iterasi Desain

Evaluasi menyeluruh dilakukan setelah prototipe diuji selama beberapa minggu. Kami mengumpulkan data teknis dan feedback pengguna untuk mengidentifikasi kekurangan dan peluang peningkatan.

Beberapa iterasi dilakukan pada desain mekanik untuk meningkatkan kemudahan penggantian media tanam, memperbaiki sistem ventilasi, dan mengoptimalkan tata letak sirkuit. Di sisi perangkat lunak, kami menyempurnakan algoritma penyiraman dan penyesuaian ekspresi.

Pendekatan iteratif ini menjamin MoodPot terus berkembang menjadi produk yang lebih baik, dengan fungsi yang lebih handal dan desain yang lebih menarik.

Dokumentasi Desain dan Panduan Pengguna

Dokumentasi lengkap mengenai desain MoodPot disusun dengan detail mulai dari gambar skematik elektronik, diagram mekanik, hingga panduan instalasi dan penggunaan. Dokumentasi ini dibuat agar pengguna dapat dengan mudah memahami fungsi dan cara merawat MoodPot.

Panduan pengguna berisi | langkah-langkah | penggunaan sistem
penyiraman otomatis, cara membaca ekspresi LED, serta tips perawatan tanaman agar tetap sehat. Kami juga menyertakan FAQ dan troubleshooting sederhana agar pengguna bisa mengatasi masalah kecil secara mandiri.

Dokumentasi ini sangat membantu dalam memperluas jangkauan
pengguna | dan | memberikan | nilai | tambah | dalam | pengalaman
menggunakan MoodPot.

Keberlanjutan dan Material Ramah Lingkungan

Kami sangat memperhatikan aspek keberlanjutan dalam pembuatan MoodPot. Bahan utama pot menggunakan plastik PLA yang biodegradable, ramah lingkungan, dan dapat didaur ulang. Material ini juga ringan dan mudah dibentuk sesuai desain yang kami inginkan.

Komponen elektronik dipilih yang hemat energi dan didukung dengan sistem power management untuk mengurangi konsumsi listrik. Kami juga merancang MoodPot agar mudah diperbaiki dan tidak cepat dibuang, sehingga mengurangi limbah elektronik.

Selain itu, MoodPot mendorong pengguna untuk lebih peduli terhadap tanaman dan lingkungan, dengan memberikan pengalaman interaktif yang edukatif dan menyenangkan.

Rencana Pengembangan dan Peningkatan Produk

Ke depannya, kami berencana menambahkan fitur konektivitas seperti Bluetooth atau Wi-Fi agar MoodPot bisa terhubung ke aplikasi smartphone. Dengan begitu, pengguna dapat memantau kondisi tanaman secara real-time dan mengatur sistem penyiraman dari jarak jauh.

Kami juga mempertimbangkan penambahan sensor tambahan seperti sensor suhu dan pH tanah untuk memberikan informasi lebih lengkap tentang kondisi tanaman. Integrasi AI sederhana akan memungkinkan MoodPot belajar dari pola penggunaan dan kondisi lingkungan untuk mengoptimalkan perawatan tanaman secara otomatis.

Pengembangan ini bertujuan membuat MoodPot semakin pintar, interaktif, dan relevan dengan kebutuhan pengguna modern.

Kesimpulan Bab 6

Bab 6 ini menguraikan perjalanan kami dalam merancang MoodPot yang menggabungkan teknologi dan estetika dengan sangat cermat. Dari desain fisik pot, penempatan komponen elektronik, hingga sistem penyiraman otomatis dan ekspresi LED matrix yang interaktif, semua dibuat dengan tujuan memberikan pengalaman terbaik bagi pengguna.

Pendekatan desain yang mengutamakan fungsi dan seni memastikan MoodPot tidak hanya menjadi alat bercocok tanam, tetapi juga sebuah objek yang membawa nilai emosional dan edukatif. Proses iterasi dan pengujian yang mendalam membuat produk ini semakin matang dan siap untuk digunakan dalam kehidupan sehari-hari.

Dengan desain yang modular dan ramah lingkungan, MoodPot memiliki potensi untuk terus berkembang dan beradaptasi dengan teknologi masa depan, sekaligus mendukung gaya hidup yang lebih sadar akan alam dan teknologi.

# BAB 7

### 7.1 Proses Perakitan MoodPot

Proses perakitan MoodPot merupakan tahap krusial yang menentukan keberhasilan proyek ini secara keseluruhan. Dalam tahap ini, semua komponen elektronik dan mekanik dipasang dengan presisi agar sistem bisa bekerja optimal. Komponen utama yang dirakit meliputi sensor kelembapan tanah, LED matrix untuk ekspresi, mikrokontroler sebagai otak sistem, pompa air mini, dan rangkaian pengatur daya.

Perakitan dimulai dengan penempatan sensor kelembapan tanah yang harus diletakkan tepat di area akar tanaman agar data yang dihasilkan akurat. Pemasangan sensor ini membutuhkan kehati-hatian karena kabel dan sambungan harus rapi serta tidak mengganggu akar tanaman. Selanjutnya, LED matrix dipasang di bagian depan pot, sehingga ekspresi yang dihasilkan bisa terlihat jelas oleh pengguna. Pemasangan LED matrix juga harus memperhatikan koneksi kabel dan polaritas LED agar tidak terjadi kerusakan saat diaktifkan.

Mikrokontroler, yang berfungsi sebagai pusat pengolah data dan kendali MoodPot, diletakkan di bagian belakang pot atau di dalam casing khusus agar terlindung dari air dan kotoran. Kabel-kabel dari sensor dan LED matrix disambungkan ke mikrokontroler dengan konektor yang kuat namun mudah dilepas jika diperlukan perawatan.

Pompa air mini juga dipasang di dalam reservoir air yang berada di dasar pot. Reservoir ini berfungsi sebagai tempat penyimpanan air untuk sistem penyiraman otomatis. Pemasangan pompa harus memperhatikan arah aliran air dan sambungan selang agar tidak bocor dan pompa dapat bekerja dengan maksimal.

Setelah semua komponen terpasang, dilakukan uji coba awal dengan memberikan daya ke sistem untuk memeriksa apakah semua komponen bisa berfungsi sesuai dengan perancangan. Uji coba ini juga untuk mendeteksi adanya koneksi yang longgar atau salah sambung.
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

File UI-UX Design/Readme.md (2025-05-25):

# ✨ UI/UX Design Showcase

Selamat datang di repositori ini! Berikut adalah hasil desain antarmuka pengguna (UI/UX) yang saya buat menggunakan Figma.

## 🔗 Figma Design Link



> Klik tombol di atas untuk melihat desain lengkap di Figma.

## 🌐 Online Web
just website maybe for commercial propose
👉 [https://moodpot.streamlit.app/](https://moodpot.streamlit.app/)

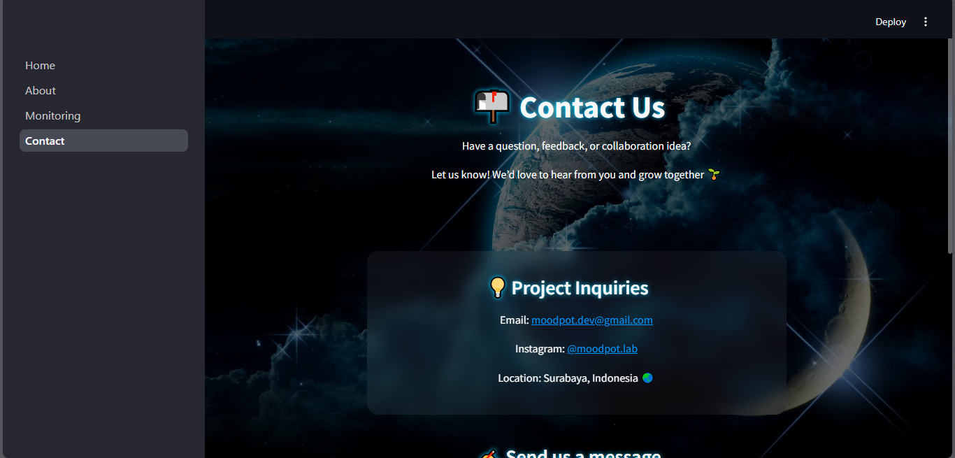
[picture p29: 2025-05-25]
UI-UX Design/Contact Us.png

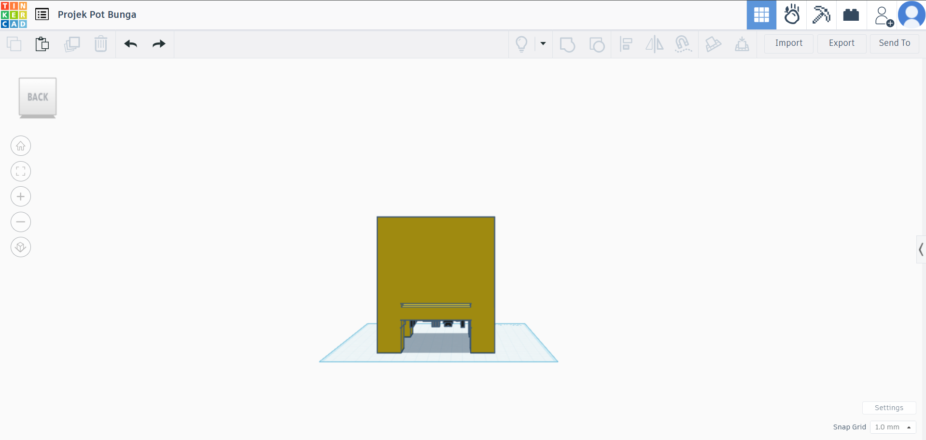
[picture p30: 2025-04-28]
3D Design/Dari Belakang.png

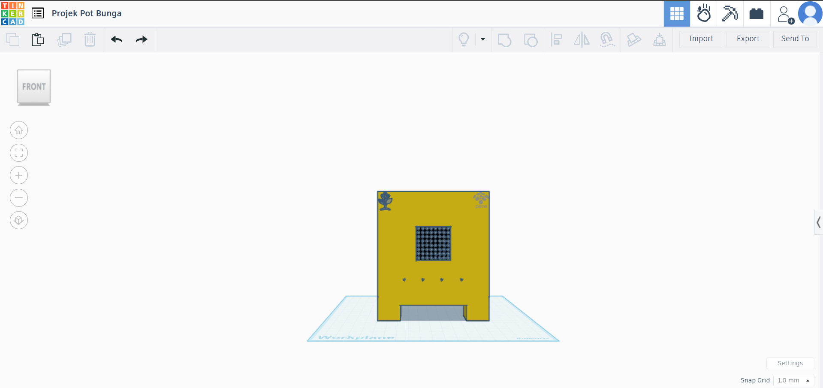
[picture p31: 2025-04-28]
3D Design/Dari Depan.png

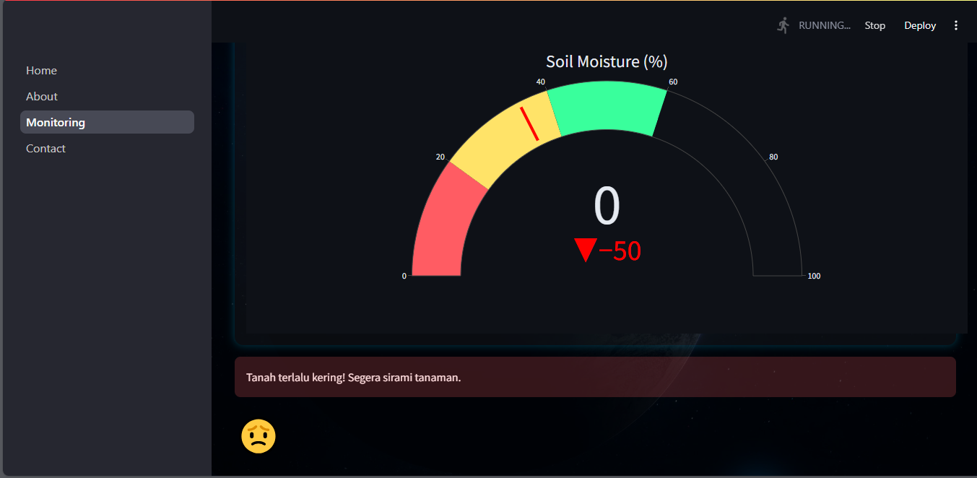
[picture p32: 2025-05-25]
UI-UX Design/Monitoring2.png

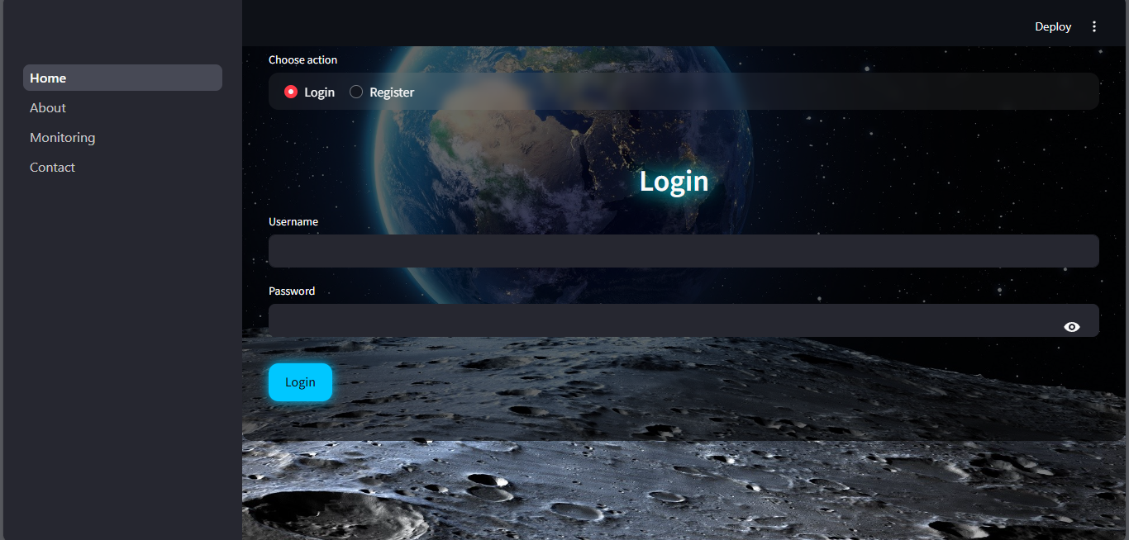
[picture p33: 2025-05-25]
UI-UX Design/Login.png

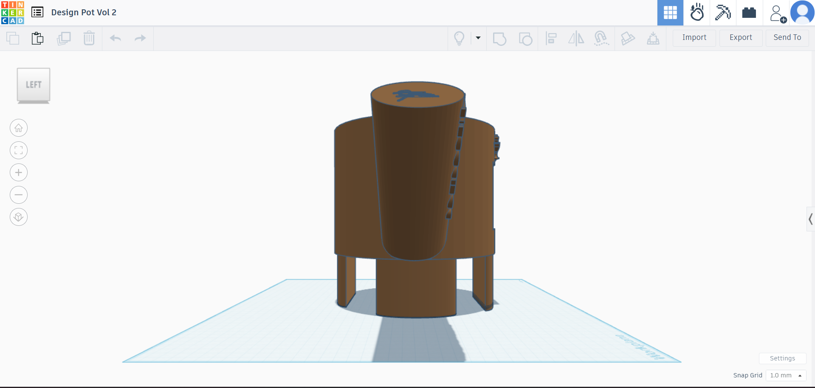
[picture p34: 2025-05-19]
3D Design/POT 2/Left.png

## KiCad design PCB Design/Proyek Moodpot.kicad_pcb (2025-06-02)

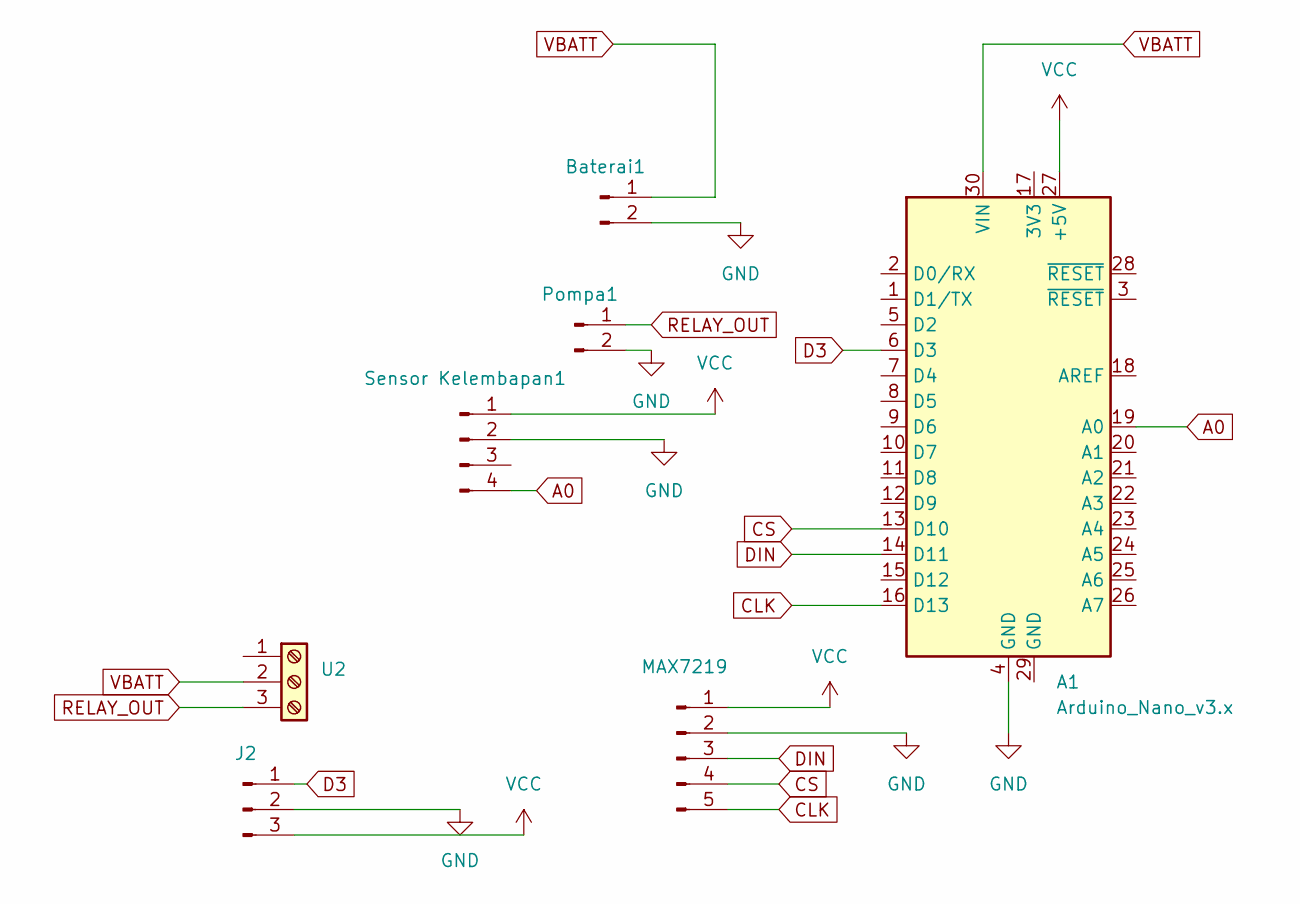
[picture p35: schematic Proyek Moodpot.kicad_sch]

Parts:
A1: Arduino_Nano_v3.x; Arduino_Nano_WithMountingHoles
Baterai1: JST_PH_B2B-PH-K_1x02_P2.00mm_Vertical
J2: Conn_01x03_Pin; FanPinHeader_1x03_P2.54mm_Vertical
MAX7219: Conn_01x05_Pin; JST_PH_B5B-PH-K_1x05_P2.00mm_Vertical
Pompa1: JST_PH_B2B-PH-K_1x02_P2.00mm_Vertical
Sensor Kelembapan1: JST_PH_B4B-PH-K_1x04_P2.00mm_Vertical
U2: Screw_Terminal_01x03; TerminalBlock_MetzConnect_Type073_RT02603HBLU_1x03_P5.08mm_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

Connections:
A0: A1.19 (A0), Sensor Kelembapan1.4
CLK: A1.16 (D13), MAX7219.5
CS: A1.13 (D10), MAX7219.4
D3: A1.6 (D3), J2.1
DIN: A1.14 (D11), MAX7219.3
GND: A1.4 (GND), Baterai1.2, J2.2, MAX7219.2, Pompa1.2, Sensor Kelembapan1.2
RELAY_OUT: Pompa1.1, U2.3
VBATT: A1.30 (VIN), Baterai1.1, U2.2
VCC: A1.27 (+5V), J2.3, MAX7219.1, Sensor Kelembapan1.1

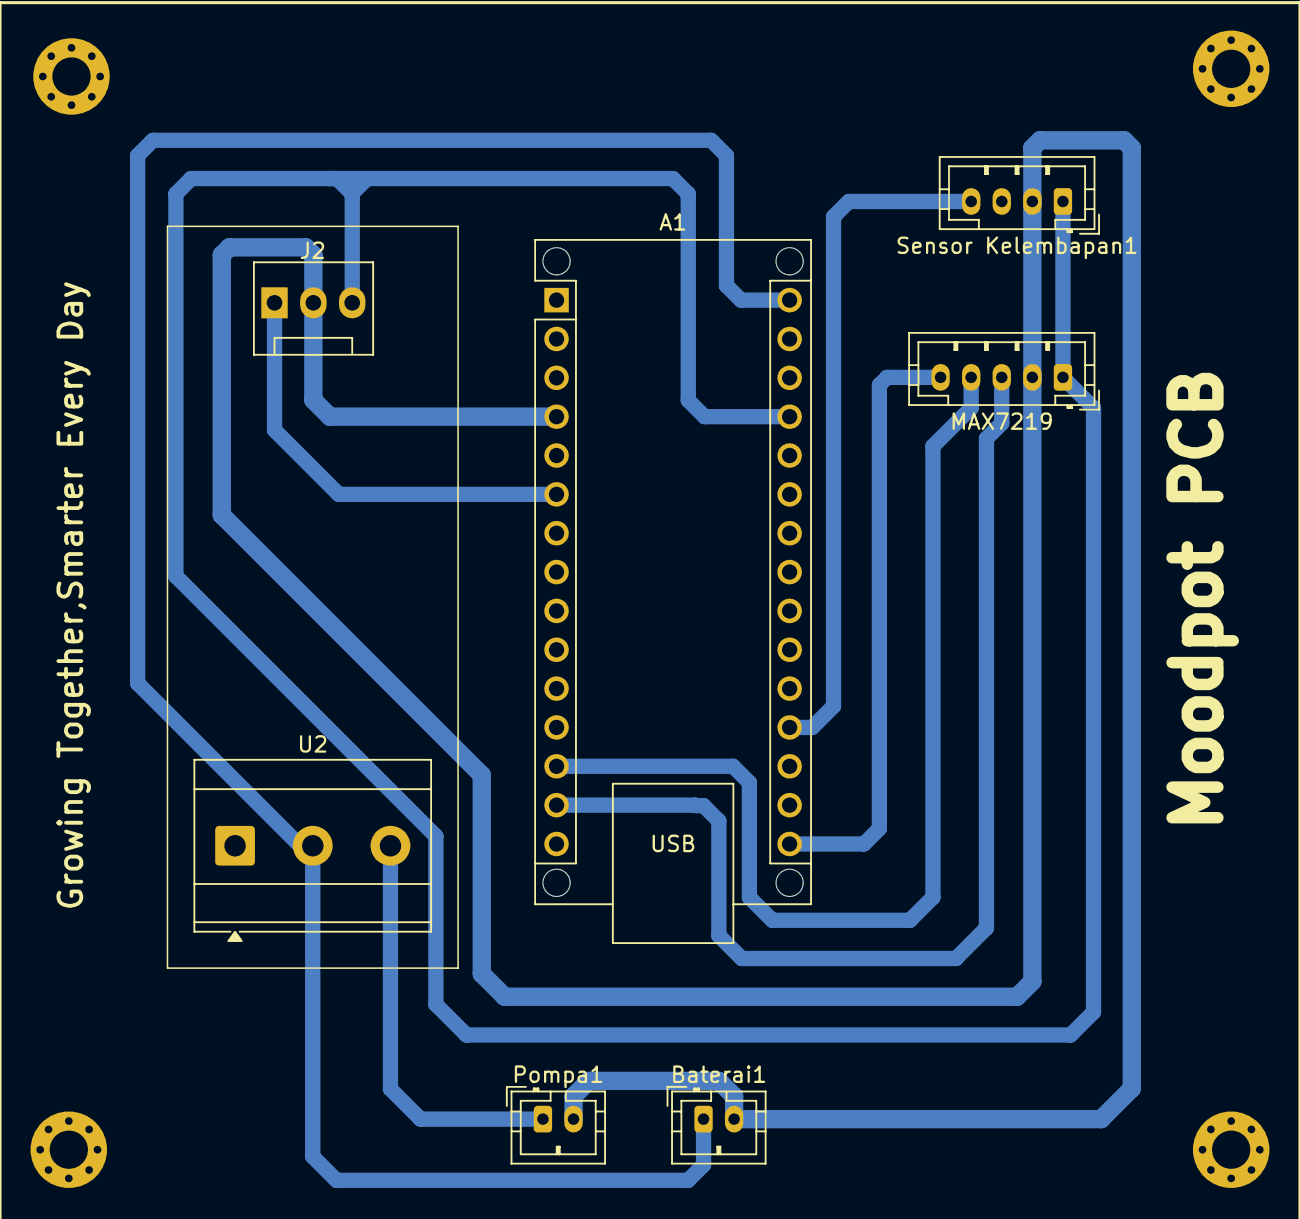
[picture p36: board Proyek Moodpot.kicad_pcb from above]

Board: 2 copper layers, 7 parts (0 on the bottom side), 9 nets.

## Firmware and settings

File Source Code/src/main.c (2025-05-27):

#include <avr/io.h>
#include <util/delay.h>
#include "usart.h"
#include "spi.h"

#define F_CPU 16000000UL

#define SENSOR_PIN 0      // ADC0
#define PUMP_PIN   PD3    // Digital pin 3

// Wajah 8x8
uint8_t sadFace[8] = {
  0b10000001,
  0b01111110,
  0b00000000,
  0b00000000,
  0b00011000,
  0b00000000,
  0b10011001,
  0b01100110
};


uint8_t neutralFace[8] = {
  0b01111110,
  0b01111110,
  0b00000000,
  0b00111100,
  0b00000000,
  0b11100111,
  0b11100111,
  0b00000000
};


uint8_t happyFace[8] = {
  0b00111100,
  0b01000010,
  0b00000000,
  0b00011000,
  0b00011000,
  0b01000010,
  0b10100101,
  0b01000010
};


void initADC() {
    ADMUX  = (1 << REFS0); // AVcc reference
    ADCSRA = (1 << ADEN)  | (1 << ADPS2) | (1 << ADPS1); // Enable ADC, prescaler 64
}

uint16_t readADC(uint8_t ch) {
    ADMUX = (ADMUX & 0xF0) | (ch & 0x0F); // Select channel
    ADCSRA |= (1 << ADSC);               // Start conversion
    while (ADCSRA & (1 << ADSC));        // Wait to finish
    return ADC;
}

void sendCommand(uint8_t address, uint8_t data) {
    PORTB &= ~(1 << PB2); // CS LOW
    spi_send(address);
    spi_send(data);
    PORTB |= (1 << PB2);  // CS HIGH
}

void initMAX7219() {
    sendCommand(0x09, 0x00);
    sendCommand(0x0A, 0x08);
    sendCommand(0x0B, 0x07);
    sendCommand(0x0C, 0x01);
    sendCommand(0x0F, 0x00);
    for (uint8_t i = 1; i <= 8; i++) sendCommand(i, 0x00);
}

void showFace(uint8_t *face) {
    for (uint8_t i = 0; i < 8; i++) {
        sendCommand(i + 1, face[i]);
    }
}

int main(void) {
    DDRD |= (1 << PUMP_PIN);
    PORTD &= ~(1 << PUMP_PIN);
    
    usart_init(9600);
    spi_init();
    initADC();
    initMAX7219();

    while (1) {
        uint16_t moisture = readADC(SENSOR_PIN);
        uint8_t percent = 100 - ((moisture * 100UL) / 1023);
        usart_print_number(percent);
        usart_send('\n');

        if (percent <= 20) {
            PORTD |= (1 << PUMP_PIN);
            showFace(sadFace);
        } else if (percent <= 40) {
            PORTD &= ~(1 << PUMP_PIN);
            showFace(neutralFace);
        } else {
            PORTD &= ~(1 << PUMP_PIN);
            showFace(happyFace);
        }

        _delay_ms(1000);
    }
}

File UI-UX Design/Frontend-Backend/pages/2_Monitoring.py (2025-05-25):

import streamlit as st
import serial
from serial.tools import list_ports
import plotly.graph_objects as go
from streamlit_autorefresh import st_autorefresh
from check_auth import require_login

require_login()

with open("style.css") as f:
    st.markdown(f"<style>{f.read()}</style>", unsafe_allow_html=True)

# ======= CSS Styling =======
st.markdown(
    """
    <style>
    .stApp {
        background-image: url('https://w.wallhaven.cc/full/5w/wallhaven-5w79w5.jpg');
        background-size: cover;
        background-repeat: no-repeat;
        background-attachment: fixed;
        background-position: center;
    }

    .block-container {
        background-color: rgba(0, 0, 0, 0.6);
        padding: 2rem;
        border-radius: 12px;
    }
    </style>
    """,
    unsafe_allow_html=True,
)

# --- Inisialisasi session_state ---
if "serial_conn" not in st.session_state:
    st.session_state.serial_conn = None
if "serial_status" not in st.session_state:
    st.session_state.serial_status = "❌ Disconnected"
if "com_port" not in st.session_state:
    st.session_state.com_port = None
if "baudrate" not in st.session_state:
    st.session_state.baudrate = None
if "monitoring" not in st.session_state:
    st.session_state.monitoring = False
if "history" not in st.session_state:
    st.session_state.history = []

st.title("Realtime Monitoring Kelembapan Tanah")

def get_serial_ports():
    ports = list_ports.comports()
    return [port.device for port in ports]

def read_moisture():
    try:
        conn = st.session_state.serial_conn
        if conn and conn.is_open:
            line = conn.readline().decode('utf-8').strip()
            if line.isdigit():
                return int(line)
        return None
    except:
        return None

# --- Panel Pengaturan Serial ---
with st.expander("Pengaturan Serial", expanded=True):
    ports = get_serial_ports()
    selected_port = st.selectbox("Pilih Port COM", ports, index=ports.index(st.session_state.com_port) if st.session_state.com_port in ports else 0)
    selected_baud = st.selectbox("Pilih Baudrate", [9600, 115200, 4800, 19200], index=[9600, 115200, 4800, 19200].index(st.session_state.baudrate) if st.session_state.baudrate else 0)
    timeout = st.slider("Timeout (detik)", min_value=0.1, max_value=1.0, value=0.1, step=0.1)


    col1, col2 = st.columns(2)
    with col1:
        if st.button("Connect"):
            try:
                if st.session_state.serial_conn:
                    st.session_state.serial_conn.close()
                conn = serial.Serial(selected_port, selected_baud, timeout=timeout)
                st.session_state.serial_conn = conn
                st.session_state.serial_status = "Connected"
                st.session_state.com_port = selected_port
                st.session_state.baudrate = selected_baud
                st.success(f"Terhubung ke {selected_port} @ {selected_baud} bps")
            except Exception as e:
                st.session_state.serial_conn = None
                st.session_state.serial_status = "Disconnected"
                st.error(f"Gagal connect: {e}")

    with col2:
        if st.button("Disconnect"):
            if st.session_state.serial_conn:
                st.session_state.serial_conn.close()
                st.session_state.serial_conn = None
                st.session_state.serial_status = "Disconnected"
                st.success("Disconnected")

    st.markdown("---")
    st.markdown(f"**Port:** `{st.session_state.com_port}`")
    st.markdown(f"**Baudrate:** `{st.session_state.baudrate}`")
    st.markdown(f"**Status:** {st.session_state.serial_status}")

# --- Monitoring Controls ---
start_stop_col1, start_stop_col2 = st.columns(2)
with start_stop_col1:
    if st.button("Start Monitoring"):
        if st.session_state.serial_status == "Connected":
            st.session_state.monitoring = True
            st.session_state.history = []
        else:
            st.warning("Hubungkan dulu ke serial sebelum mulai monitoring!")

with start_stop_col2:
    if st.button("Stop Monitoring"):
        st.session_state.monitoring = False

# --- Autorefresh hanya jika monitoring aktif ---
if st.session_state.monitoring:
    count = st_autorefresh(interval=1000, limit=None, key="autorefresh_counter")
    moisture = read_moisture()
    if moisture is not None:
        st.session_state.history.append(moisture)
    else:
        moisture = st.session_state.history[-1] if st.session_state.history else 0

    # Tampilkan gauge
    fig = go.Figure(go.Indicator(
        mode="gauge+number+delta",
        value=moisture,
        delta={'reference': 50, 'increasing': {'color': "lime"}, 'decreasing': {'color': "red"}},
        gauge={
            'axis': {'range': [0, 100]},
            'bar': {'color': "#00c7ff"},
            'steps': [
                {'range': [0, 20], 'color': "#ff6666"},
                {'range': [20, 40], 'color': "#ffe066"},
                {'range': [40, 60], 'color': "#66ff99"}
            ],
            'threshold': {
                'line': {'color': "red", 'width': 4},
                'thickness': 0.75,
                'value': 35
            }
        },
        title={'text': "Soil Moisture (%)", 'font': {'size': 24}}
    ))
    st.plotly_chart(fig, use_container_width=True)


    def emoji_large(emoji_char):
        return f"<p style='font-size:48px; margin:0'>{emoji_char}</p>"

    if moisture < 20:
        st.error("Tanah terlalu kering! Segera sirami tanaman.")
        st.markdown(emoji_large("😟"), unsafe_allow_html=True)
    elif 20 <= moisture <= 40:
        st.warning("Kelembapan cukup. Periksa secara berkala.")
        st.markdown(emoji_large("😐"), unsafe_allow_html=True)
    else:
        st.success("Tanah lembab dan sehat.")
        st.markdown(emoji_large("😊"), unsafe_allow_html=True)



else:
    st.info("Tekan Start Monitoring untuk mulai membaca data dari Arduino.")

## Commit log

2025-05-12 Create desain pcb
2025-05-14 Create pcb
2025-05-18 Rename Screenshot 2025-05-16 211504.png to Schematic.png
2025-05-18 Rename Screenshot 2025-05-16 213700.png to 3D Viewer PCB.png
2025-06-06 Rename PCB Design/WhatsApp Image 2025-06-02 at 11.42.02_abeca7d9.jpg to Tampilan Dalamjpg
2025-06-06 Rename Tampilan Dalamjpg to PCB Design/Tampilan Dalam.jpg
